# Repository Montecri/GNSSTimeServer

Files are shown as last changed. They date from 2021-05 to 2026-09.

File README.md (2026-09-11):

# <p align="center">Stratum-1 GNSS Time Server Built From Scratch-GNSSTimeServer</p>

<p align="center">
  <!-- Row 1: live repo stats -->
  
  
  
  
  
</p>
<p align="center">
  <!-- Row 2: what the project IS -->
  
  
  
  
  
  
  

<p align="center">
  <a href="https://github.com/Montecri/GNSSTimeServer/releases?q=ntp-rdate-">
    
  </a>
  <a href="https://github.com/Montecri/GNSSTimeServer/releases?q=ptp-master-">
    
  </a>
  <a href="https://github.com/Montecri/GNSSTimeServer/releases?q=ptp-slave-">
    
  </a>
</p>
  
</p>

<p align="center">
  <a href="https://github.com/Montecri/GNSSTimeServer/tree/main/src/PTP/README.md" target="_blank">
    
  </a>
</p>

<p align="center">
  <strong>
    <a href="https://github.com/Montecri/GNSSTimeServer/tree/main/src/PTP/README.md">
      GNSS Time Server: The PTPv2 Edition
    </a>
  </strong>
</p>

<br>

<p align="center"><a href="https://docs.google.com/forms/d/e/1FAIpQLSchZhBenU4u7z4XQDj6ZXXRinHSWwy8loy8uxbl7-j-GinHIg/viewform" target="_blank">
 Answer Survey
 <b>Answer the survey: Crowdfunding for GNSS Time Server</b>
 </a></p>

<br>





## 📡 Ethernet/WiFi enabled, GNSS fed, NTP/RDATE/PTP server based on ESP8266/ESP32 and Arduino

<br>

🎖️ Featured by [Hackaday](https://hackaday.com/2021/07/25/portable-gps-time-server-powered-by-the-esp8266/)

🎖️ Selected for and presented at [Maker Faire Rome 2023](https://makerfairerome.eu/en/exhibitors/?edition=2023&exhibit=2320015)

🎖️ Selected for and presented at [Maker Faire Curitiba 2026](https://www.makerfairecuritiba.com.br/)

<br>

## 📸 Maker Faire Rome 2023 Pictures
<br>

|  |  |  |  |
|:-:|:-:|:-:|:-:|
|  |  |  |  |
|  |  |  |  |

<p align="center">

<br>

"Buy Me A Coffee" (https://www.buymeacoffee.com/cristmon)

<br>

</p>

---

## ✨ Functionalities

- **Internal real-time clock (RTC)** with an integrated temperature-compensated crystal oscillator (TCXO), synched from Global Navigation Satellite System (GNSS) satellites constellation (GPS, BeiDou, GLONASS and Galileo; backed by CR2032 battery)
- **Real-time operating system (RTOS) multi-tasking** (when used with ESP32); core tasks (GNSS synching, Clock updating, processing NTP/RFC868 requests) running with a higher priority than common tasks (display update, PPS led blinking, web page serving)
- **Rich dashboard** with information about MCU, RTC, GNSS, WiFi (uptime, free heap, minimum heap, temperature, version, IP, mac address, network name, network type, signal strength, timestamp, lat, long, lock status, sats, precision, etc)
- **Highly optimized web page** (minimalist single HTML with no external dependency, embedded graphics (as base64 encoded strings, including favicon), embedded script and layout, gzip-compressed - Python conversion/compression script supplied), requiring a password for critical functions. Only 32 Kb in size total, further reduced to ~20Kb through GZip compression. All modern browsers support gzipped pages, the compression takes place before firmware compiling, so no computing cycle is wasted by the device
  - Data separated from layout, once the page is loaded, data will be updated every 5 seconds from a lightweight JSON string, no full page reloads are needed
- **Over-The-Air (OTA)** Web Based firmware upgrade
- **Dual voltage powered**
- **Backup battery** for the whole unit (18650)
- **NTP and RDATE (RFC868)** protocols supported
- **WiFi functionality** as a client or access point
- **10/100 Mbps Ethernet support** (W5500 hardwired TCP/IP embedded Ethernet controller)
- **Syslog logging**
- **Configuration webpage** for WiFi and Syslog, saving to persistent storage (LittleFS)
- **Informative display** with a timestamp, satellites in view, accuracy, WiFi server, IP address
- **Dual function button**, short press switch information on display, long press toggles WiFi
- **Status at a glance**, with dedicated 5mm LEDs for GPS lock, PPS signal, and WiFi status, as well as visible internal leds for charging and GPS module statuses
  - Yellow LED will be on or off to indicate respective WiFi status
  - Green LED will blink/pulsate at different rates to indicate a lock is being acquired and stay steady green when locked
  - Red LED will blink once a second once the lock is acquired, in sync with the PPS signal
- **Diagnostics messages on boot**
  - When turned on, the OLED will first display the reason for the last shutdown (if it was rebooted by the MCU itself due to a power oscillation or other reason or if it was a user-triggered shutdown) and proceed displaying the startup status of each module, so if it gets stuck on boot you can know which module is hanging and troubleshoot faster.

> [!NOTE]
> Please note that some functionalities are available only on ESP32, due to either ESP8266 limitation or the functionality not being backported yet.

---

## 🧰 Parts list

- Amica NodeMCU (ESP8266 / ESP-12) **or** ESP32Duino (ESP32-WROOM-32)
- DS3231 RTC
- **GNSS module. Tested with:** Neo-6m V2 · ATGM336H · ZKMICRO AT6558D · TOPGNSS Allystar TAU1201
- 1.3" SH1106 OLED Display
- **For mains powered:** Hi-Link 5V/3W · Mini-360 DC-DC Buck converter · TP4056 Module · 18650 battery holder · 0.5A/230v fuse · 10D561K varistor
- **For power adapter powered:** 18650 battery shield · 5.5mm x 2.1 mm or any other suitable socket
- **For the ethernet-enabled version:** WIZNet W5500 module
- Resistors (150, 100, and 150 Ohms respectively for above LEDs)
- Switch key and momentary push button

<p align="center"><b>New dashboard screenshot:</b></p>


<p align="center"><b>And the new 3D printable case:</b></p>


<br>

> [!TIP]
> **Check also the Dual Display PIR Enabled branch option:**
> https://github.com/Montecri/GPSTimeServer/tree/Dual-Display

---

## ⚠️ Before you build — read these

<p align="center"><b>   ATTENTION   </b></p>

> [!CAUTION]
> Several DS3231 modules being sold today contain a hazardous design flaw in which it supplies a voltage to the battery cradle regardless if it came with a rechargeable battery or not. If it came with a CR2032 battery (non-rechargeable) the consequence is that it will swell, explode, or worse. If it comes with a LIR2032 battery (rechargeable), the module is fed with 5v will generate an unsafe charging voltage for that battery.
>
> There are workarounds for that so you don't need to toss your module away, the most popular being removing a diode and/or resistor.
>
> There's a long discussion on the thread below about the root cause and possible fixes:
>
> https://forum.arduino.cc/t/zs-042-ds3231-rtc-module/268862/33

<p align="center">
  <b>   GNSS BPS NOTICE   </b>
</p>

> [!IMPORTANT]
> Please note that the vast majority of GNSS modules come pre-configured for 9600 bps serial communication. While this supposedly is a fit for the GPS communication, it may not be enough for other GNSS networks, which work or may work with faster speeds.
>
> So, you will find in the code that I favor 115200 for GNSS module bps speed, which is the practical limit and works great if you set your GNSS module to 10Hz as opposed to the default 1Hz updates, for the modules I tested.
>
> There's a number of applications capable of changing a GNSS module frequency and bps; one I know that works for several module brands is called GnssToolKit3.

---

## 📚 Libraries

```
Libraries:
  paulstoffregen/Time   @ ^1.6
  makuna/RTC            @ ^2.3.5
  mikalhart/TinyGPSPlus @ ^1.0.3
  olikraus/U8g2         @ ^2.28.8
  arcao/Syslog          @ ^2.0.0
```

**Source code based on:**

- http://w8bh.net/avr/clock2.pdf
- https://forum.arduino.cc/t/ntp-time-server/192816

**Contributions from:**

- @mmarkin
- @sjthespian

---

## 🔌 Wiring & power diagrams

<b>ESP8266 Wiring Diagram:</b>

sketch_bb-menor

<br/><br/>

<b>ESP32 Wiring Diagram:</b>

sketch-ESP32-20250308_bb

<br/><br/>

<b>ESP32 With Ethernet Wiring Diagram:</b>

sketch-ESP32_With_ETH-20250308_bb

<br/><br/>

<b>Power Supply Diagram:</b>

power supply - UPDATED_bb-menor

---

📰 https://www.linkedin.com/pulse/iot-maker-tale-stratum-1-time-server-built-from-scratch-monteiro/

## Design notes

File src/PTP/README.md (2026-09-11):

# <p align="center">GNSS Time Servers Built From Scratch - The PTPv2 Edition</p>

<p align="center">
  <!-- Row 1: live repo stats (repo-wide, shields.io can't scope these to a subdirectory) -->
  
  
  
  
  
</p>
<p align="center">
  <!-- Row 2: what THIS subtree IS (PTP Grandmaster + Slave) -->
  
  
  
  
  
  
  
  
  
</p>



<br>

🎖️ Featured by [Hackaday](https://hackaday.com/2026/07/08/this-diy-time-server-is-more-accurate-than-you-need/)

🎖️ Selected for and presented at [Maker Faire Curitiba 2026](https://www.makerfairecuritiba.com.br/)
<br><br>

Two homemade time servers, one obsession: turning a noisy one-pulse-per-second tick from the GPS satellites overhead into a clock the rest of your network can trust. They come from the same workbench and the same stubborn insistence on building from scratch, they differ only in **how precise you need to be**.

- 🛰️ The **GNSS Time Server** speaks **NTP and RDATE** and keeps a whole network honest to the **millisecond**. Portable, battery-backed, WiFi-enabled, happy in a HAM shack, a home lab, or a field bag.
- 📡 The **PTP Grandmaster** speaks **PTPv2 (IEEE 1588-2008)** and disciplines a wired Ethernet segment to the **sub-microsecond**, for industrial automation, telecom, broadcast, finance, and instrumentation, where "close enough" stopped being close enough.

Same maker, same itch, three orders of magnitude apart.

<br>

📰 The story behind both builds, in two parts:
*[An IoT Maker Tale: Stratum-1 Time Server Built From Scratch](https://www.linkedin.com/pulse/iot-maker-tale-stratum-1-time-server-built-from-scratch-monteiro/)*, and its sequel, *[An IoT Maker Tale, Part II: From Stratum-1 NTP to a Sub-Microsecond PTP Grandmaster](https://www.linkedin.com/pulse/iot-maker-tale-part-ii-from-stratum-1-ntprdate-ptpv2-monteiro-ja6ef)*.

<br>

"Buy Me A Coffee" (https://www.buymeacoffee.com/cristmon)

---

## 🧭 Which one is for you?

Both are GNSS-disciplined, self-contained, dissectable-from-the-inside time sources built on inexpensive microcontrollers, with the same maker-friendly DNA an informative OLED, a push button to cycle screens, status LEDs, and a web dashboard. The table is the fastest way to choose; the rest of this README walks through *why* each row is what it is.

| | 🛰️ **GNSS Time Server** | 📡 **PTP Grandmaster** |
| --- | --- | --- |
| **Protocols** | NTP + RDATE (RFC 868) | PTPv2 (IEEE 1588-2008), Layer-2 Ethernet |
| **Typical accuracy** | Milliseconds across the network | **Sub-microsecond** (mean error −74 ns) |
| **Brain** | ESP8266 / ESP32 + Arduino | ESP32-P4 + ESP-IDF |
| **Timestamping** | Software | **Hardware** (ESP32-P4 on-chip PTP-capable EMAC) |
| **Connectivity** | WiFi + 10/100 Ethernet (W5500) | Wired Gigabit Ethernet (IP101 PHY) |
| **Holdover clock** | DS3231 TCXO, battery-backed | On-chip PHC + software servo |
| **Power** | Dual (mains + 18650), portable | USB-C |
| **Field-ready** | Yes, runs on battery, WiFi out of the box | Bench / rack, wired Ethernet by nature |
| **Best for** | Home labs, HAM shacks, general sync, field use | Industrial, telecom, broadcast, finance, instrumentation |

The short version: reach for the **GNSS Time Server** when you want a portable box that keeps any network's clocks accurate and runs anywhere. Reach for the **PTP Grandmaster** when milliseconds aren't enough and you need wired sub-microsecond precision.



<br>

---

## 🛰️ Where time comes from

Both devices start at the same place: the constellation of GPS / GNSS satellites overhead, each carrying atomic clocks accurate to about a second every few hundred million years, a free Stratum-0 reference floating over our heads. A GNSS module locks onto them and emits two things that matter: the current time, and a **Pulse Per Second (PPS)**, a clean (almost) 1 Hz electrical edge marking the top of each second.

That PPS edge is the heartbeat. Everything downstream is a question of how faithfully you can capture it and how cleanly you can pass it on.

- The **GNSS Time Server** disciplines a battery-backed **DS3231 TCXO** real-time clock from the satellites and answers NTP/RDATE requests. The temperature-compensated crystal holds time gracefully during satellite outages.
- The **PTP Grandmaster** goes further: it captures the PPS edge *inside the GPIO interrupt* and uses it to discipline the ESP32-P4's on-chip **PTP Hardware Clock (PHC)** through a software servo, then hardware-timestamps PTP frames as they leave the wire. No external RTC, the servo itself "remembers" the crystal's drift and coasts through brief outages.

The single biggest lever on precision is the GNSS module. A navigation-grade receiver (NEO-6m, ATGM336H) assumes it's moving and constantly re-estimates its position, and that noise rides straight onto the PPS edge. A **timing-mode** receiver like the **AllyStar TAU1201** knows it's stationary and spends its math on the time solution instead, dropping PPS jitter from hundreds of nanoseconds to roughly **10 ns**. The GNSS Time Server works beautifully with either; the PTP Grandmaster's sub-microsecond numbers depend on it.

<p align="center"><a href="http://www.youtube.com/watch?feature=player_embedded&v=QWhQtFGGHVM" target="_blank">
 Watch the video
</a>

---

## ⭐ What both share and where they part ways

Everything below is organized by capability, comparing the two builds side by side. Where a feature belongs to only one device, it's marked 🛰️ (NTP/RDATE) or 📡 (PTP); shared traits are marked 🤝.

### 🔌 Connectivity & protocols

- 🛰️ **NTP and RDATE (RFC 868)** served over WiFi (client *or* access point) and 10/100 Mbps Ethernet via a hardwired **W5500** controller.
- 📡 **PTPv2 over Layer-2 Ethernet** (Annex F) raw frames, no IP/UDP overhead, with two-step **Sync + Follow_Up**, **Announce**, and **Delay_Req / Delay_Resp** exchanges, on wired Gigabit through an **IP101** PHY.
- 📡 **Plug-and-play addressing** DHCP first, automatic static-IP fallback after 15 s if no server replies. (The NTP build offers WiFi configuration via its web page instead.)
- 🤝 Both come up on the network with no hand-holding and announce themselves clearly once linked.

> [!IMPORTANT]
> **PTP belongs on wired Ethernet, never WiFi.** The protocol's sub-microsecond accuracy assumes a deterministic, hardware-timestamped physical layer; WiFi's association, retry, and queueing jitter would swamp it entirely. The NTP/RDATE server, by contrast, is perfectly at home on WiFi, millisecond-class accuracy tolerates it comfortably.

### ⏱️ The clock and its discipline

- 🛰️ **DS3231 TCXO RTC**, satellite-synched and CR2032-backed, with PPS aligning the top-of-second.
- 📡 **On-chip PHC** steered by a three-state software servo (`UNLOCKED → ACQUIRING → LOCKED`): a coarse step on acquisition, a fine residual correction, then a slow **PID loop** whose derivative term tracks the thermal transients of a crystal warming up, hundreds of ppb/sec of drift that an integrator alone is too slow to catch.
- 📡 A **32-sample running-mean averager** (≈5.7× noise reduction) is the servo's working signal, and frequency corrections are **slew-rate-limited** so the servo physically cannot chase a transient faster than the averager smooths it.
- 📡 **TAI ↔ UTC** handling (37 s offset, configurable for future leap seconds).

### 🛰️ GNSS interface & signal diagnostics

- 🤝 **Multi-constellation NMEA** GPS, GLONASS, Galileo, BeiDou (plus QZSS / multi-GNSS GN talker on the PTP build).
- 📡 **PPS captured inside the ISR**, eliminating 10–50 µs of FreeRTOS scheduling jitter that would otherwise be injected straight into the offset measurement.
- 📡 Live **signal-quality telemetry**: per-constellation SNR (avg/min/max), satellites in view vs. used, satellite churn (PRN entries/exits per window), and PPS edge-to-edge jitter (min/max/mean-abs/outliers).
- 📡 **Fix-validity gating** time is only trusted when RMC confirms a valid fix, so a coasting receiver can't feed stale time into the servo.

### 🧭 Grandmaster behaviour (📡 PTP only)

- **Best Master Clock Algorithm (BMCA)** with full priority1 / clockClass / accuracy / variance / priority2 / clockIdentity ordering, so multiple grandmasters can coexist and fail over gracefully.
- A **stability filter** that requires 3 consecutive Announces from the same candidate before changing roles, and a **6-second announce timeout** before reclaiming the master role, together giving the master role a clean hysteresis that shields downstream slaves from needless flapping.
- **Dynamic clock quality** advertising: clockClass 6 / accuracy 0x21 when locked, 7 / 0x23 in holdover, with a 30-second post-holdover settling window so recovering slaves don't rail their servos against a still-settling master.
- **Slave tracking**, up to 8 simultaneous slave clock IDs with a 30-second activity timeout.

### 🛡️ Holdover & resilience

- 🛰️ The **DS3231 TCXO** keeps time through satellite outages; the unit is **dual-powered** (mains + 18650) so it rides out power blips too.
- 📡 **Smart holdover** distinguishes a *sentence-only* outage (NMEA stopped but PPS still alive, preserve all learned servo state) from a *true* PPS loss (re-acquire from scratch).
- 📡 A **self-healing watchdog** can restart the EMAC while preserving PHC continuity across the ~120 ms dead window, slaves see one missed Sync, not a full re-acquire, backed by PHC-freeze and heap-pressure detection, torn-read protection on the PHC second-boundary, and a leak-free pure-arithmetic `timegm`.

### 🖥️ Status at a glance: display, button, LEDs, dashboard

This is the maker-friendly heart both devices share: you can read their health across the room, drill in with one button, or pull up a full dashboard from a browser.

- 🤝 An **OLED display** with a **push button** to cycle informative screens, plus **status LEDs** and a **web dashboard**. No laptop required to know what's going on.
- 🛰️ **Boot diagnostics** report the reason for the last shutdown and the start-up status of each module, so if it ever hangs on boot, you know exactly which module to blame. A **dual-function button** short-presses to switch the display and long-presses to toggle WiFi. Dedicated 5 mm LEDs cover GPS lock, PPS, and WiFi; a rich web dashboard reports MCU / RTC / GNSS / WiFi telemetry (uptime, heap, temperature, IP, MAC, satellites, precision, lat/long, and more), updated every 5 seconds from a lightweight JSON string with no full-page reloads. The page is a single gzip-compressed HTML under ~20 KB with no external dependencies, password-protected for critical functions, and supports **OTA firmware upgrades**.
- 📡 **Five navigable screens** 📊 Main (lock state, UTC, offset, GNSS status, active slaves), ⚙️ Servo (lock duration, quality %, peak spread, frequency adjustment, integrator, PPS count), 📡 GNSS Signal (verdict, SNR range, SVs in view vs. used, fix quality), 🌐 Network (link, IP, uptime, heap), and 🔧 Timing Config (TAU1201 configurator status, which **auto-jumps into view on failure**). The lock LED has five distinct patterns, off (no link), slow blink (acquiring), solid (locked), heartbeat (holdover), fast blink (fault), and a second LED pulses on **every PPS edge**.

---

## 🧰 Parts

### 🛰️ GNSS Time Server

- Amica NodeMCU (ESP8266 / ESP-12) **or** ESP32Duino (ESP32-WROOM-32)
- DS3231 RTC
- GNSS module, tested with Neo-6m V2, ATGM336H, ZKMICRO AT6558D, TOPGNSS AllyStar TAU1201
- 1.3" SH1106 OLED display
- **Mains-powered:** Hi-Link 5V/3W · Mini-360 DC-DC buck · TP4056 module · 18650 holder · 0.5 A/230 V fuse · 10D561K varistor
- **Adapter-powered:** 18650 battery shield · 5.5 × 2.1 mm (or suitable) socket
- **Ethernet version:** WIZnet W5500 module
- Resistors (150, 100, 150 Ω for the LEDs) · and a momentary push button

### 📡 PTP Grandmaster

- **JC-ESP32P4-M3-DEV (Guition board)** (Espressif), hardware PTP-capable EMAC
- **AllyStar TAU1201** GNSS module, configured in timing mode
- **IP101** Ethernet PHY (on-board on the EV-Board variant used here)
- 1.3″ SH1106 OLED (128×64, I²C, address `0x78`)
- Momentary push button · 5 mm LEDs (lock + PPS) with current-limiting resistors
- Active GPS antenna with clear sky view
- RJ45 cable (Cat 5e+, for back-to-back testing - No crossover needed for connecting two JC-ESP32P4-M3-DEV since they are MDI/MDIX)
- 5 V supply (USB-C)

> [!TIP]
> The **TAU1201 is the single highest-impact part choice** in either build, and the make-or-break one for the PTP grandmaster. A navigation-grade receiver works, the firmware accepts NMEA from any of them, but PPS jitter will be hundreds of nanoseconds rather than ~10 ns, and the achievable accuracy scales with it. If the budget allows, fit the TAU1201.

> [!NOTE]
> On the NTP/RDATE build, some functionalities are ESP32-only, due either to ESP8266 limitations or features not yet backported.

---

## 🛠️ Building each one

The two devices use **different toolchains** this is the clearest practical fork between them.

**🛰️ GNSS Time Server: Arduino / PlatformIO**

```
Libraries:
  paulstoffregen/Time @ ^1.6
  makuna/RTC          @ ^2.3.5
  mikalhart/TinyGPSPlus @ ^1.0.3
  olikraus/U8g2       @ ^2.28.8
  arcao/Syslog        @ ^2.0.0
```

**📡 PTP Grandmaster: ESP-IDF 5.5.4**

```
Libraries:
  olikraus/U8g2           @ ^2.36.19
  mkfrey/u8g2-hal-esp-idf @ ^v3-compat
```

> [!IMPORTANT]
> On its first boot in a new location, the PTP grandmaster spends a few minutes on a **TAU1201 position survey** before timing-mode engages, screen 5 shows progress. This is part of the timing mode process activation, it will compute it's current location during this window and then revert to timing only calculation.

---

## 🧪 Measuring sub-microsecond honestly (📡 PTP)

A grandmaster's accuracy claim is only as good as the instrument measuring it. A software-timestamping slave on a generic PC would drown sub-microsecond behaviour in its own kernel jitter, so the measurement instrument has to be at least as good as the device under test. The project, therefore, includes a **companion slave unit on identical ESP32-P4 hardware**, with its own hardware-timestamped state machine, servo, OLED, button, LEDs, and web dashboard reporting offset, path delay, and lock quality.

```
   ┌──────────────────┐                    ┌──────────────────┐
   │  GPS antenna     │                    │                  │
   │       │          │                    │                  │
   │       ▼          │   Ethernet cable   │                  │
   │  ESP32-P4 GM     │◄──────────────────►│  ESP32-P4 Slave  │
   │  (this repo)     │       100 Mbps     │  (sibling repo)  │
   │                  │                    │                  │
   │  OLED + LEDs     │                    │  OLED + LEDs     │
   └──────────────────┘                    └──────────────────┘
```

Captured by that slave, on a typical evening with the antenna on the balcony:

| Metric | Value |
| --- | --- |
| 🎯 Within ±300 ns of true GPS time | ~30% |
| 🎯 Within ±1 µs | ~74% |
| 🎯 Within ±2 µs | ~89% |
| 📏 Mean error | −74 ns |
| ⏱️ Cold-boot lock time | ~30 s |
| 🛰️ Raw PPS jitter (TAU1201, timing mode) | ~10 ns |
| 🔄 EMAC-restart PHC continuity | < 1 µs residual |

For context, commercial PTP grandmasters delivering similar numbers typically start north of **US$2,000**. The bill of materials here, for *both* master and slave, is closer to a nice dinner.

> [!NOTE]
> **What's next:** a **PTP-capable switch** (transparent- or boundary-clock function preferred) to run multiple slaves against the master at once, and a third unit configured as a boundary clock. Switched-network testing is where the interesting questions surface, master load scaling, BMCA failover under real witnesses, switch-induced residence delay. Yes, I understand commercial units come with high-quality OCXO parts, rubidium oscillators, certifications, etc, but still...

---

## ⚠️ Before you build, read these

<p align="center"><b>   ATTENTION   </b></p>

🚨 **GNSS serial speed (both builds).** Most GNSS modules ship at 9600 bps. That's fine for GPS alone, but can be too slow for multi-constellation work. The code favors **115200 bps**, which is the practical limit and pairs well with raising the module from 1 Hz to 10 Hz updates. Tools like *GnssToolKit3* can change a module's rate and baud across several brands.

🚨 **PTP needs wired Ethernet (📡 PTP).** Never attempt PTP over WiFi, association/retry/queueing jitter dwarfs the protocol's accuracy budget and no servo tuning can recover it.

🚨 **TAU1201 timing mode after a survey (📡 PTP).** First boot in a new location takes several minutes to reach `READY` while the module surveys its position. Survey window is configurable in `allystar_timing.h`.

🚨 **Domain 0 by default (📡 PTP).** The grandmaster announces on PTP domain 0 and will join the BMCA election on any network already running PTP there. Set a different domain in `main.c` (`#define PTP_DOMAIN`) before deploying alongside existing infrastructure.

🚨 **GNSS time is TAI, not UTC (📡 PTP).** The firmware advertises `currentUtcOffset = 37` and sets `PTP_TIMESCALE` on the wire. Slave software that treats PTP timestamps as UTC will be off by the TAI−UTC offset. This is correct per IEEE 1588, just worth knowing when integrating with software that's never met a proper grandmaster.

---

## 🤖 A note on AI tooling

The first build, three years ago, was stitched together by hand from two PDFs and an Arduino-forum thread. The second would not have reached this caliber, in the time one person had, without the generation of AI tools available in 2026. Yes, the code is heavily built by AI. Don't like it? Go there and fix!

The PID tuning still had to be measured against reality. The interrupt path still had to be debugged on real hardware. The architectural decisions are still mine to defend. But AI compressed weeks of reading and experimenting into hours and let a single maker take on the scope of *two* firmware codebases, grandmaster and slave, in one project cycle. For anyone hesitating to start something that feels too large: the tools have changed, and the barrier is lower than you think.

---

## 📚 Related & lineage

- 🛰️ [**GNSSTimeServer**](https://github.com/Montecri/GNSSTimeServer): the NTP/RDATE server, featured by Hackaday and exhibited at Maker Faire Rome 2023
- 🔀 [**Dual Display PIR-Enabled branch**](https://github.com/Montecri/GPSTimeServer/tree/Dual-Display): an alternative build of the NTP/RDATE server
- 📡 **PTPGrandmaster**: the sub-microsecond follow-up (this project)
- 📡 **PTPGrandmasterSlave**: the companion slave used to validate the PTP numbers above

---

## 🙏 Acknowledgements

The NTP/RDATE server stands on the shoulders of [w8bh.net](http://w8bh.net/avr/clock2.pdf) and the [Arduino NTP time-server thread](https://forum.arduino.cc/t/ntp-time-server/192816), with contributions from @mmarkin and @sjthespian. The PTP grandmaster stands on the open-source PTP community, Espressif's ESP-IDF PTP examples, and the IEEE 1588 specification itself. And all stand on everyone who sent feedback over the years and asked me to pursue a PTP version of the GNSSTimeServer, that community is the reason there's a Part II.

---

"Buy Me A Coffee" (https://www.buymeacoffee.com/cristmon)

73 📻

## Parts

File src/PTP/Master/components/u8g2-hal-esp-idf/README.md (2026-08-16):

# U8g2 compatibility component for ESP-IDF on ESP32
## Note
This is effectively a fork of the U8G2 code that is part of Neil Kolban's excellent `esp32-snippets` repository. It can be found 
[here](https://github.com/nkolban/esp32-snippets/tree/master/hardware/displays/U8G2).

His repository is no longer maintained and using a single directory as submodule is not possible. So I copied the relevant
files and made them a functional component for ESP-IDF by creating the required build system files.

This component should compile on ESP-IDF versions 5.x upward. Older versions are not supported.

## Description
There is an excellent open source library called `u8g2` that can be found on Github here:

[https://github.com/olikraus/u8g2](https://github.com/olikraus/u8g2)

The purpose of the library is to provide a display independent driver layer for monochrome displays including LCD and OLED.
The library "knows" how to driver the underlying displays as well as providing drawing primitives including text, fonts, lines and
other geometrical shapes.

A version of the library is available in cleanly compiling C and compiles without incident on the ESP32-IDF framework.

However, since the library is agnostic of MCU environments and will work on a variety of boards, there has to be a mapping from
the functions expected by the library to the underlying MCU board hardware. This includes driving GPIOs, I2C, SPI and more.

The code in this folder provides a mapping from U8g2 to the ESP32 ESP-IDF. This should be included in your build of U8g2 applications.

To use with the ESP32, we must invoke the `u8g2_esp32_hal_init()` function before invoking any of the normal U8g2 functons.  What
this call does is tell the ESP32 what pins we wish to map.  Here is an example of SPI use:

```
u8g2_esp32_hal_t u8g2_esp32_hal = U8G2_ESP32_HAL_DEFAULT;
u8g2_esp32_hal.bus.spi.clk   = PIN_CLK;
u8g2_esp32_hal.bus.spi.mosi  = PIN_MOSI;
u8g2_esp32_hal.bus.spi.cs    = PIN_CS;
u8g2_esp32_hal.dc    = PIN_DC;
u8g2_esp32_hal.reset = PIN_RESET;
u8g2_esp32_hal_init(u8g2_esp32_hal);
```

and here is an example of I2C use:

```
u8g2_esp32_hal_t u8g2_esp32_hal = U8G2_ESP32_HAL_DEFAULT;
u8g2_esp32_hal.bus.i2c.sda = PIN_SDA;
u8g2_esp32_hal.bus.i2c.scl = PIN_SCL;
u8g2_esp32_hal_init(u8g2_esp32_hal);
```

Note: For I2C, after calling the display specific setup, invoke:

```
u8x8_SetI2CAddress(&u8g2.u8x8,<address>);
``` 

Note that `<address>` is the I2C address already shifted left to include the read/write flag.  For example, if you are using an SSD1305, instead of supplying the address `0x3C` which would be `0011 1100` supply `0x78` which would be `0111 1000`.

The function takes as input a `u8g2_esp32_hal` structure instance which has the logical pins that U8g2 needs mapped to the
physical pins on the ESP32 that we wish to use.  If we don't use a specific pin for our specific display, set the value to
be `U8G2_ESP32_HAL_UNDEFINED` which is the default initialization value.

Remember, ESP32 pins are not hard-coded to functions and as such, all the GPIO pins on the ESP32 are open for use.  Following
this initialization, we can use U8g2 as normal and described in the U8g2 documentation.

## Installation
To use the actual U8g2 library in your ESP32 project, perform the following steps:

1. Create a directory called `components` in your main project directory.
2. Change into the `components` directory.
3. Run `git clone https://github.com/mkfrey/u8g2-hal-esp-idf.git` to bring in the latest copy of this library.
4. Run `git clone https://github.com/olikraus/u8g2.git` to bring in a the latest copy of u8g2 library.

If your project itself is a git repository, you should consider using `git submodule add` instead of cloning.

## Development
While in principal, there should be nothing specific needed beyond this addition to make U8g2 work on the ESP32, only a small
number of boards have been tested.

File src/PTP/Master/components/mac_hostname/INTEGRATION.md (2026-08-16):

# mac_hostname — deterministic, fully reversible MAC → hostname

Turns the device's Ethernet MAC into a stable, human-friendly hostname
(`prefix-title-first-last`, e.g. `fabled-roper-susanda-perrhale`) and
back. The mapping is **bijective over the entire 2^48 MAC space**:
every MAC yields a distinct hostname, and any generated hostname
decodes to exactly its MAC — no collisions, no lookup registry.

## Layout in the project

```
your-project/
├── main/
│   └── main.c                     <- one buffer-size edit, see below
└── components/
    └── mac_hostname/
        ├── CMakeLists.txt
        ├── include/
        │   └── mac_hostname.h     <- public API
        ├── mac_hostname.c         <- codec (Feistel + encode + decode)
        ├── mac_hostname_esp.c     <- mac_hostname_get / mac_hostname_apply
        ├── name_data.c            <- AUTOGENERATED tables (~10 KB flash)
        ├── name_data.h            <- AUTOGENERATED struct + externs
        ├── INTEGRATION.md         <- this file
        └── tools/                 <- not compiled into the firmware
            ├── name_components.py <- curated word/stem/ending lists
            ├── emit_c_data.py     <- regenerates name_data.c/h
            ├── sample_names.py    <- PC codec + full self-test
            ├── emit_c_data.json   <- table dump used by sample_names.py
            └── host_selftest.c    <- PC test of the real C sources
```

No top-level CMakeLists.txt change is needed: ESP-IDF auto-discovers
`components/`, and the `main` component automatically depends on every
discovered component. (If your `main/CMakeLists.txt` lists explicit
`PRIV_REQUIRES`, add `mac_hostname` there.)

## Required edit in main.c

The v3 scheme's worst-case "first-last" OLED line is 17 chars + NUL:

```c
static char g_host_line2[16];   /* before */
static char g_host_line2[24];   /* after  */
```

`g_host_line1[24]` and `g_hostname[MAC_HOSTNAME_BUF_LEN]` are already
correctly sized. Nothing else in main.c changes —
`mac_hostname_get()`, `mac_hostname_apply()` and
`mac_hostname_display_lines()` keep their signatures.

Kconfig: `CONFIG_LWIP_MAX_HOSTNAME_LEN` must be >= 32 (hostnames are
15..31 chars).

## How it works

`MAC --feistel_forward--> 48-bit index --split--> 8|7|17|16 bits`

| bits | token  | construction |
|---|---|---|
| 8 | prefix | 256 real adjectives (≤ 6 ch) |
| 7 | title  | 128 real English roles/ranks (≤ 6 ch) |
| 17 | first  | 256 stems × 512 endings (3–8 ch) |
| 16 | last | 256 roots × 256 suffixes (3–8 ch) |

First/last names are composed, not stored: the stem tables are
**prefix-free** (no stem is a prefix of another), which makes
`stem+ending` concatenation provably injective and lets the decoder
recover the split with a deterministic prefix scan. Decoding is
case-insensitive. Worst-case dashed length is 31 (+ NUL = 32).

## Regenerating or tuning the tables

The component lists in `tools/name_components.py` are plain curated
lists — edit to taste, then:

```
cd components/mac_hostname/tools
python3 emit_c_data.py          # re-proves all invariants, writes
cp name_data.c name_data.h ..   # tables next to the sources
python3 sample_names.py test    # full self-test (bijectivity, 100k)
```

`emit_c_data.py` machine-checks every invariant before writing
anything: exact table sizes, prefix-freeness, exhaustive uniqueness of
all 2^17 + 2^16 concatenations, the 31-char worst case and the 3-char
minimum. If an edit breaks a proof, it refuses to emit.

Note: editing the tables (or the Feistel keys in `emit_c_data.py`)
changes every device's hostname on the next flash.

## PC-side verification

```
cd components/mac_hostname
gcc -Wall -Wextra -O2 -Iinclude -I. -o /tmp/mh_test \
    mac_hostname.c name_data.c tools/host_selftest.c && /tmp/mh_test
```

Runs the real firmware sources on the host: sample MACs, round-trips,
case-insensitive decode, display-line buffer checks, and 100 000
random MACs verified unique and reversible. `sample_names.py` is the
independent Python implementation; both produce identical output
(e.g. `dc:1e:d5:f8:b2:d8 → dulcet-keeper-vicant-pecklund`), so you can
decode a hostname seen in DHCP/mDNS back to its MAC on a PC with
`sample_names.py`, or on-device with `mac_hostname_to_mac()`.

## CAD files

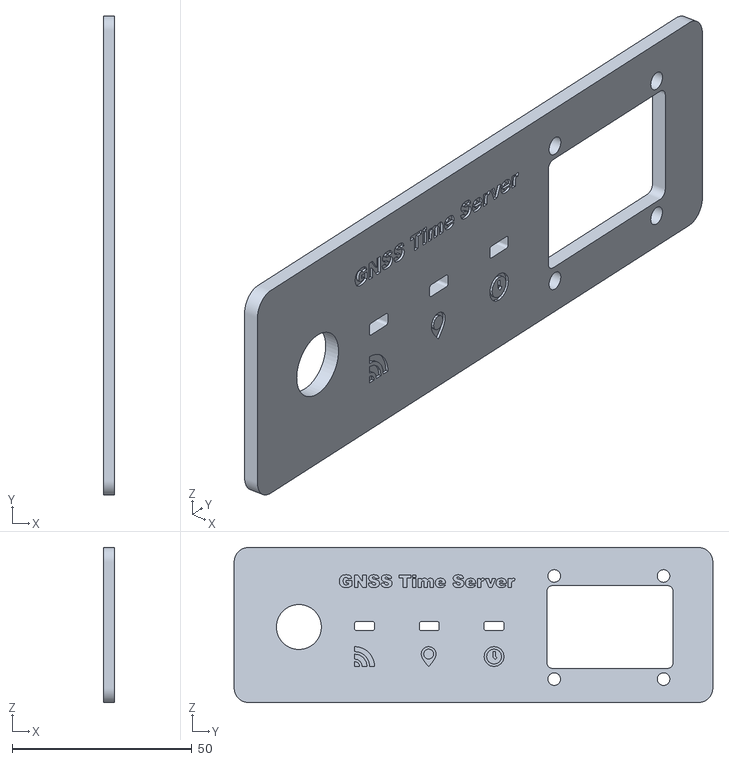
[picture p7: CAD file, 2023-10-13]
resources/3DPrintableCase/Case_Ver2-FPanel.stl
3.00 x 133.1 x 43.1

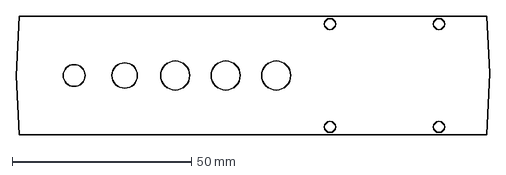
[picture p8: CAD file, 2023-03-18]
resources/painel_frontal-v4.DXF
132.0 x 33.0 mm

src/PTP/Master/components/u8g2/sys/arduino/u8g2_full_buffer/SwitchBox/board.dxf
60
40
52
8
24
80
30
32
25
100
190
4
12
6
14

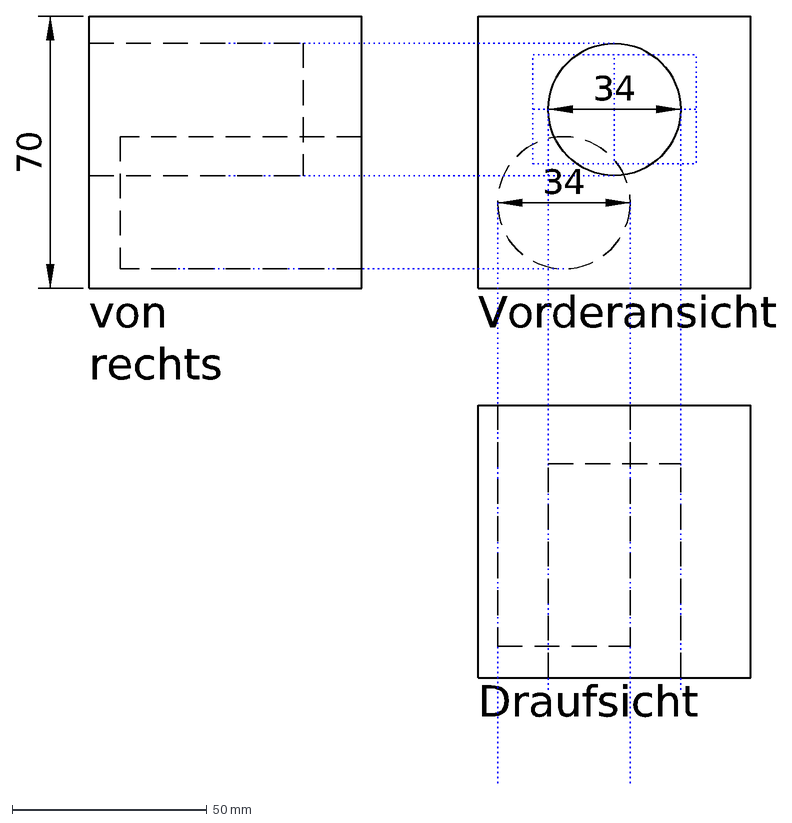
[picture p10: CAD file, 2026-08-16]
src/PTP/Master/components/u8g2/sys/arm/stm32l031x6/clock_cube.dxf
Draufsicht
Vorderansicht
von rechts
70
34

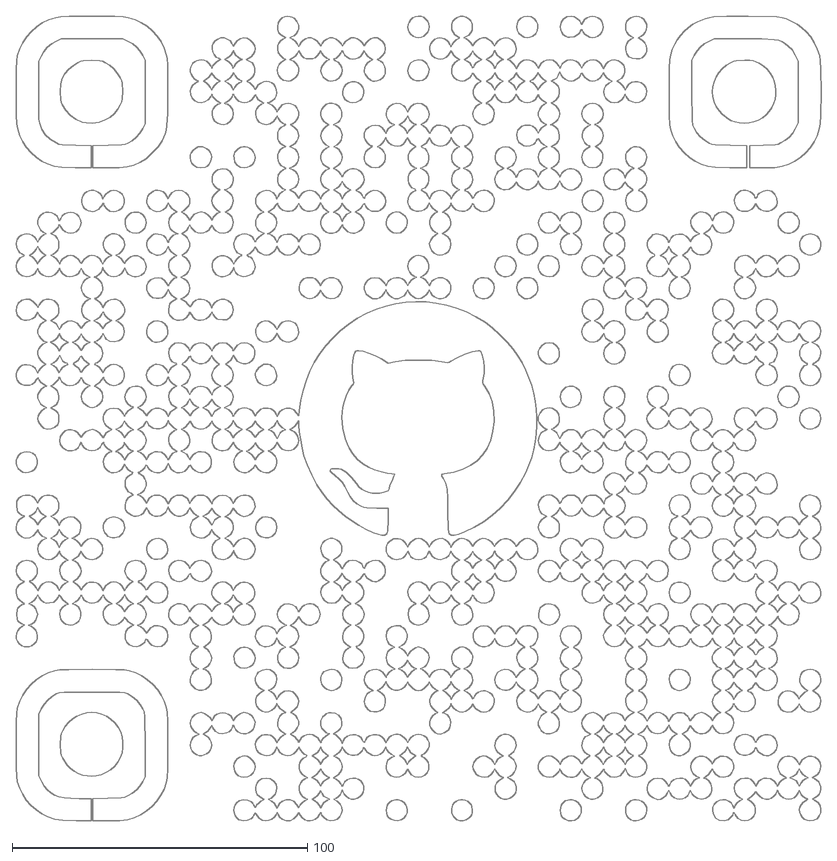
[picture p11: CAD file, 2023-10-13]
src/PTP/resources/qr-code6.dxf
272.8 x 272.8

src/PTP/Slave/components/u8g2/sys/arm/stm32l031x6/clock.dxf
65
32
28
16
Draufsicht
Vorderansicht
von unten
von rechts
von links
14
6
45
60
30
20
8
35
75
55
10
12

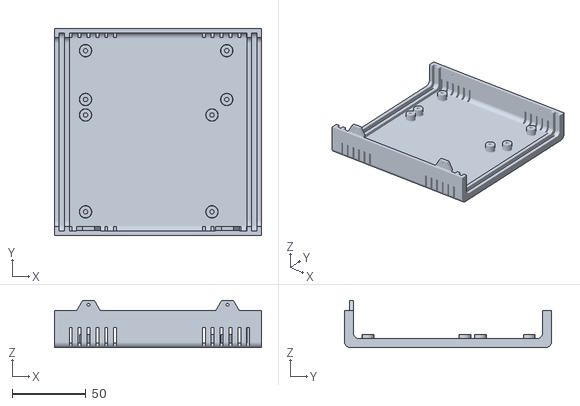
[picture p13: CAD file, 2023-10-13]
resources/3DPrintableCase/Case_Ver2-Bottom.stl
140.0 x 140.0 x 31.9

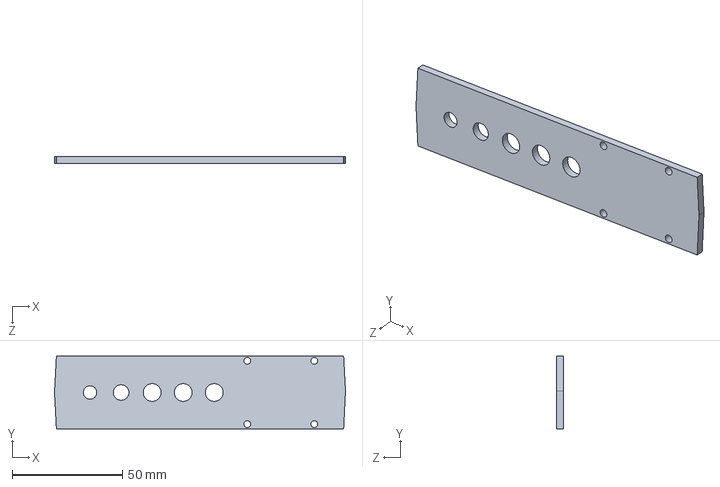
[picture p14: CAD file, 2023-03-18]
resources/painel_frontal-v4-perfurado.SLDPRT
132.0 x 33.0 x 3.00 mm

src/PTP/Master/components/u8g2/sys/arm/stm32l031x6/clock_2.dxf
65
Draufsicht
Vorderansicht
von unten
von rechts
von links
14
30
32
35
75
55
10
12
16
11
22
34
28
29
18
93
19
43
15
68
60
57
150
Holzbohrer: 2.5, 8, 10, 12, 16, 32mm
8
7
6
2.5mm

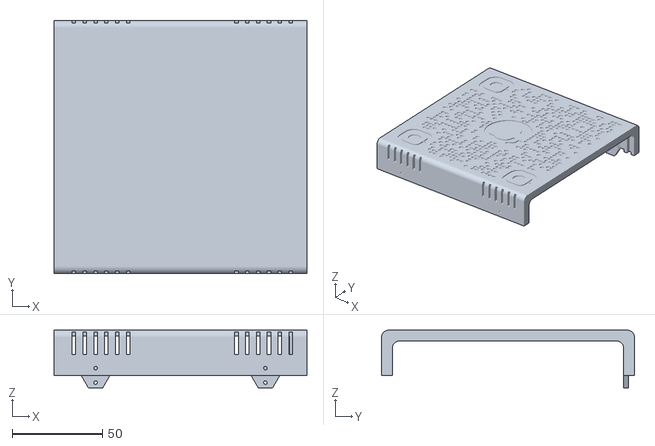
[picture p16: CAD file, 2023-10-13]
resources/3DPrintableCase/Case_Ver2-Top_Github-QR_Code.stl
140.0 x 140.0 x 31.9

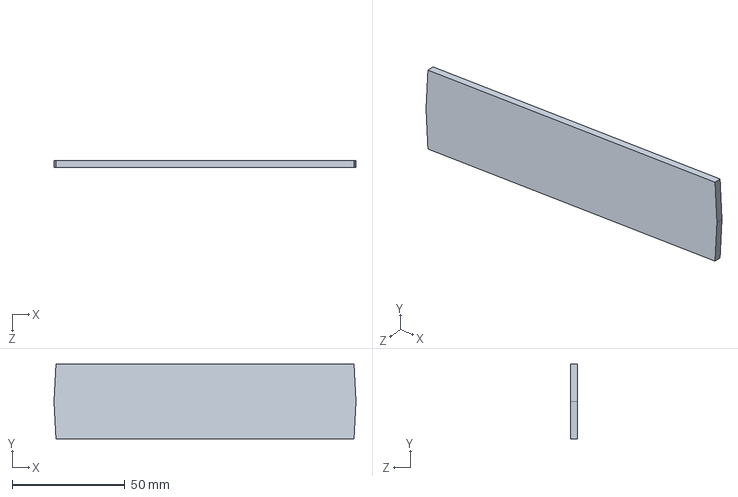
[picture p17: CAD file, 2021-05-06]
resources/painel_frontal_dimensoes.SLDPRT
133.7 x 33.0 x 3.00 mm

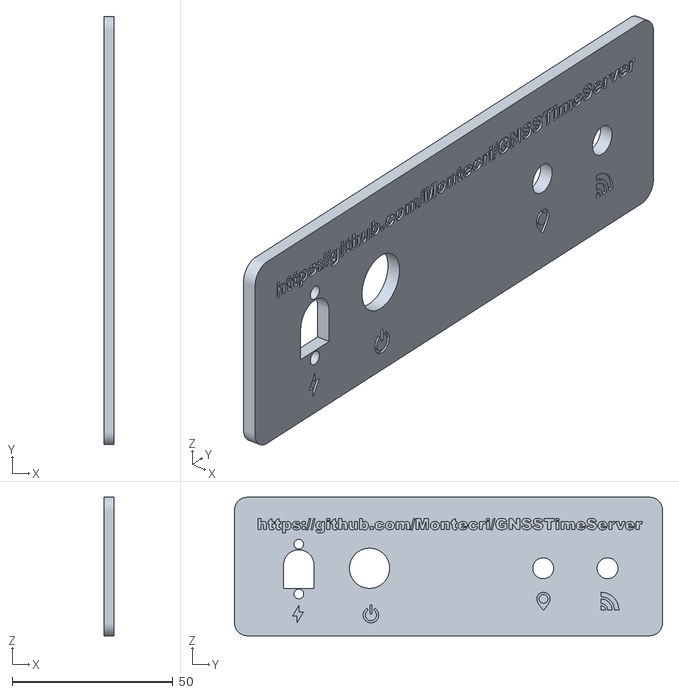
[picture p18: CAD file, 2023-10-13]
resources/3DPrintableCase/Case_Ver2-BPanel.stl
3.00 x 133.1 x 43.1

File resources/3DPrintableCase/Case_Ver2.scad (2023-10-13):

/*//////////////////////////////////////////////////////////////////
              -    FB Aka Heartman/Hearty 2016     -                   
              -   http://heartygfx.blogspot.com    -                  
              -       OpenScad Parametric Box      -                     
              -         CC BY-NC 3.0 License       -                      
////////////////////////////////////////////////////////////////////                                                                                                             
12/02/2016 - Fixed minor bug 
28/02/2016 - Added holes ventilation option                    
09/03/2016 - Added PCB feet support, fixed the shell artefact on export mode. 

*/////////////////////////// - Info - //////////////////////////////

// All coordinates are starting as integrated circuit pins.
// From the top view :

//   CoordD           <---       CoordC
//                                 ^
//                                 ^
//                                 ^
//   CoordA           --->       CoordB


////////////////////////////////////////////////////////////////////


////////// - Paramètres de la boite - Box parameters - /////////////

/* [Box dimensions] */
// - Longueur - Length  
  Length        = 140;       
// - Largeur - Width
  Width         = 140;                     
// - Hauteur - Height  
  Height        = 50;  
// - Epaisseur - Wall thickness  
  Thick         = 3;//[2:5]  
  
/* [Box options] */
// - Diamètre Coin arrondi - Filet diameter  
  Filet         = 4;//[0.1:12] 
// - lissage de l'arrondi - Filet smoothness  
  Resolution    = 50;//[1:100] 
// - Tolérance - Tolerance (Panel/rails gap)
  m             = 0.9;
// Pieds PCB - PCB feet (x4) 
  PCBFeet       = 1;// [0:No, 1:Yes]
  PCBFeet2       = 1;// [0:No, 1:Yes]
// - Decorations to ventilation holes
  Vent          = 1;// [0:No, 1:Yes]
// - Decoration-Holes width (in mm)
  Vent_width    = 2;   


  
/* [PCB_Feet] */
//All dimensions are from the center foot axis

// - Coin bas gauche - Low left corner X position
PCBPosX         = 5;
// - Coin bas gauche - Low left corner Y position
PCBPosY         = 3;
// - Longueur PCB - PCB Length
PCBLength       = 85.5;
// - Largeur PCB - PCB Width
PCBWidth        = 65.5;
// - Heuteur pied - Feet height
FootHeight      = 10;
// - Diamètre pied - Foot diameter
FootDia         = 8;
// - Diamètre trou - Hole diameter
FootHole        = 3;  
  
PCBPosX2         = 5;
// - Coin bas gauche - Low left corner Y position
PCBPosY2         = 79;
// - Longueur PCB - PCB Length
PCBLength2       = 95.5;
// - Largeur PCB - PCB Width
PCBWidth2        = 33;
// - Heuteur pied - Feet height
FootHeight2      = 10;
// - Diamètre pied - Foot diameter
FootDia2         = 8;
// - Diamètre trou - Hole diameter
FootHole2        = 3; 

/* [STL element to export] */
//Coque haut - Top shell
TShell          = 1;// [0:No, 1:Yes]
//Coque bas- Bottom shell
BShell          = 1;// [0:No, 1:Yes]
//Panneau avant - Front panel
FPanL           = 1;// [0:No, 1:Yes]
//Panneau arrière - Back panel  
BPanL           = 1;// [0:No, 1:Yes]


  
/* [Hidden] */
// - Couleur coque - Shell color  
Couleur1        = "Orange";       
// - Couleur panneaux - Panels color    
Couleur2        = "OrangeRed";    
// Thick X 2 - making decorations thicker if it is a vent to make sure they go through shell
Dec_Thick       = Vent ? Thick*2 : Thick; 
// - Depth decoration
Dec_size        = Vent ? Thick*2 : 0.8;





/////////// - Boitier générique bord arrondis - Generic rounded box - //////////

module RoundBox($a=Length, $b=Width, $c=Height){// Cube bords arrondis
                    $fn=Resolution;            
                    translate([0,Filet,Filet]){  
                    minkowski (){                                              
                        cube ([$a-(Length/2),$b-(2*Filet),$c-(2*Filet)], center = false);
                        rotate([0,90,0]){    
                        cylinder(r=Filet,h=Length/2, center = false);
                            } 
                        }
                    }
                }// End of RoundBox Module

      
////////////////////////////////// - Module Coque/Shell - //////////////////////////////////         

module Coque(){//Coque - Shell  
    Thick = Thick*2;  
    difference(){    
        difference(){//sides decoration
            union(){    
                     difference() {//soustraction de la forme centrale - Substraction Fileted box
                      
                        difference(){//soustraction cube median - Median cube slicer
                            union() {//union               
                            difference(){//Coque    
                                RoundBox();
                                translate([Thick/2,Thick/2,Thick/2]){     
                                        RoundBox($a=Length-Thick, $b=Width-Thick, $c=Height-Thick);
                                        }
                                        }//Fin diff Coque                            
                                difference(){//largeur Rails        
                                     translate([Thick+m,Thick/2,Thick/2]){// Rails
                                          RoundBox($a=Length-((2*Thick)+(2*m)), $b=Width-Thick, $c=Height-(Thick*2));
                                                          }//fin Rails
                                     translate([((Thick+m/2)*1.55),Thick/2,Thick/2+0.1]){ // +0.1 added to avoid the artefact
                                          RoundBox($a=Length-((Thick*3)+2*m), $b=Width-Thick, $c=Height-Thick);
                                                    }           
                                                }//Fin largeur Rails
                                    }//Fin union                                   
                               translate([-Thick,-Thick,Height/2]){// Cube à soustraire
                                    cube ([Length+100, Width+100, Height], center=false);
                                            }                                            
                                      }//fin soustraction cube median - End Median cube slicer
                               translate([-Thick/2,Thick,Thick]){// Forme de soustraction centrale 
                                    RoundBox($a=Length+Thick, $b=Width-Thick*2, $c=Height-Thick);       
                                    }                          
                                }                                          


                difference(){// wall fixation box legs
                    union(){
                        translate([3*Thick +5,Thick,Height/2]){
                            rotate([90,0,0]){
                                    $fn=6;
                                    cylinder(d=16,Thick/2);
                                    }   
                            }
                            
                       translate([Length-((3*Thick)+5),Thick,Height/2]){
                            rotate([90,0,0]){
                                    $fn=6;
                                    cylinder(d=16,Thick/2);
                                    }   
                            }

                        }
                            translate([4,Thick+Filet,Height/2-57]){   
                             rotate([45,0,0]){
                                   cube([Length,40,40]);    
                                  }
                           }
                           translate([0,-(Thick*1.46),Height/2]){
                                cube([Length,Thick*2,10]);
                           }
                    } //Fin fixation box legs
            }

        union(){// outbox sides decorations
            
            for(i=[0:Thick:Length/4]){

                // Ventilation holes part code submitted by Ettie - Thanks ;) 
                    translate([10+i,-Dec_Thick+Dec_size,1]){
                    cube([Vent_width,Dec_Thick,Height/4]);
                    }
                    translate([(Length-10) - i,-Dec_Thick+Dec_size,1]){
                    cube([Vent_width,Dec_Thick,Height/4]);
                    }
                    translate([(Length-10) - i,Width-Dec_size,1]){
                    cube([Vent_width,Dec_Thick,Height/4]);
                    }
                    translate([10+i,Width-Dec_size,1]){
                    cube([Vent_width,Dec_Thick,Height/4]);
                    }
  
                
                    }// fin de for
               // }
                }//fin union decoration
            }//fin difference decoration
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

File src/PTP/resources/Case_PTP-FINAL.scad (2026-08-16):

/*//////////////////////////////////////////////////////////////////
              -    FB Aka Heartman/Hearty 2016     -                   
              -   http://heartygfx.blogspot.com    -                  
              -       OpenScad Parametric Box      -                     
              -         CC BY-NC 3.0 License       -                      
////////////////////////////////////////////////////////////////////                                                                                                             
12/02/2016 - Fixed minor bug 
28/02/2016 - Added holes ventilation option                    
09/03/2016 - Added PCB feet support, fixed the shell artefact on export mode. 

09.Jul.2026 - Modified for PTP box by Cristiano Monteiro <cristianomonteiro@gmail.com>

*/////////////////////////// - Info - //////////////////////////////

// All coordinates are starting as integrated circuit pins.
// From the top view :

//   CoordD           <---       CoordC
//                                 ^
//                                 ^
//                                 ^
//   CoordA           --->       CoordB


////////////////////////////////////////////////////////////////////


////////// - Paramètres de la boite - Box parameters - /////////////

/* [Box dimensions] */
// - Longueur - Length  
  Length        = 120;       
// - Largeur - Width
  Width         = 120;                     
// - Hauteur - Height  
  Height        = 50;  
// - Epaisseur - Wall thickness  
  Thick         = 3;//[2:5]  
  
/* [Box options] */
// - Diamètre Coin arrondi - Filet diameter  
  Filet         = 4;//[0.1:12] 
// - lissage de l'arrondi - Filet smoothness  
  Resolution    = 50;//[1:100] 
// - Tolérance - Tolerance (Panel/rails gap)
  m             = 0.9;
// Pieds PCB - PCB feet (x4) 
  PCBFeet       = 0;// [0:No, 1:Yes]
  PCBFeet2       = 0;// [0:No, 1:Yes]
// - Decorations to ventilation holes
  Vent          = 1;// [0:No, 1:Yes]
// - Decoration-Holes width (in mm)
  Vent_width    = 2;   


  
/* [PCB_Feet] */
//All dimensions are from the center foot axis

// - Coin bas gauche - Low left corner X position
PCBPosX         = 1.3;
// - Coin bas gauche - Low left corner Y position
PCBPosY         = 19.4;
// - Longueur PCB - PCB Length
PCBLength       = 92;
// - Largeur PCB - PCB Width
PCBWidth        = 62;
// - Heuteur pied - Feet height
FootHeight      = 10;
// - Diamètre pied - Foot diameter
FootDia         = 8;
// - Diamètre trou - Hole diameter
FootHole        = 2;  

// Feet distance from PCB border
FeetDistBorder = 2.8;
  
PCBPosX2         = 5;
// - Coin bas gauche - Low left corner Y position
PCBPosY2         = 79;
// - Longueur PCB - PCB Length
PCBLength2       = 95.5;
// - Largeur PCB - PCB Width
PCBWidth2        = 33;
// - Heuteur pied - Feet height
FootHeight2      = 10;
// - Diamètre pied - Foot diameter
FootDia2         = 8;
// - Diamètre trou - Hole diameter
FootHole2        = 3; 

/* [STL element to export] */
//Coque haut - Top shell
TShell          = 1;// [0:No, 1:Yes]
//Coque bas- Bottom shell
BShell          = 1;// [0:No, 1:Yes]
//Panneau avant - Front panel
FPanL           = 1;// [0:No, 1:Yes]
//Panneau arrière - Back panel  
BPanL           = 1;// [0:No, 1:Yes]


  
/* [Hidden] */
// - Couleur coque - Shell color  
Couleur1        = "Orange";       
// - Couleur panneaux - Panels color    
Couleur2        = "OrangeRed";    
// Thick X 2 - making decorations thicker if it is a vent to make sure they go through shell
Dec_Thick       = Vent ? Thick*2 : Thick; 
// - Depth decoration
Dec_size        = Vent ? Thick*2 : 0.8;





/////////// - Boitier générique bord arrondis - Generic rounded box - //////////

module RoundBox($a=Length, $b=Width, $c=Height){// Cube bords arrondis
                    $fn=Resolution;            
                    translate([0,Filet,Filet]){  
                    minkowski (){                                              
                        cube ([$a-(Length/2),$b-(2*Filet),$c-(2*Filet)], center = false);
                        rotate([0,90,0]){    
                        cylinder(r=Filet,h=Length/2, center = false);
                            } 
                        }
                    }
                }// End of RoundBox Module

      
////////////////////////////////// - Module Coque/Shell - //////////////////////////////////         

module Coque(){//Coque - Shell  
    Thick = Thick*2;  
    difference(){    
        difference(){//sides decoration
            union(){    
                     difference() {//soustraction de la forme centrale - Substraction Fileted box
                      
                        difference(){//soustraction cube median - Median cube slicer
                            union() {//union               
                            difference(){//Coque    
                                RoundBox();
                                translate([Thick/2,Thick/2,Thick/2]){     
                                        RoundBox($a=Length-Thick, $b=Width-Thick, $c=Height-Thick);
                                        }
                                        }//Fin diff Coque                            
                                difference(){//largeur Rails        
                                     translate([Thick+m,Thick/2,Thick/2]){// Rails
                                          RoundBox($a=Length-((2*Thick)+(2*m)), $b=Width-Thick, $c=Height-(Thick*2));
                                                          }//fin Rails
                                     translate([((Thick+m/2)*1.55),Thick/2,Thick/2+0.1]){ // +0.1 added to avoid the artefact
                                          RoundBox($a=Length-((Thick*3)+2*m), $b=Width-Thick, $c=Height-Thick);
                                                    }           
                                                }//Fin largeur Rails
                                    }//Fin union                                   
                               translate([-Thick,-Thick,Height/2]){// Cube à soustraire
                                    cube ([Length+100, Width+100, Height], center=false);
                                            }                                            
                                      }//fin soustraction cube median - End Median cube slicer
                               translate([-Thick/2,Thick,Thick]){// Forme de soustraction centrale 
                                    RoundBox($a=Length+Thick, $b=Width-Thick*2, $c=Height-Thick);       
                                    }                          
                                }                                          


                difference(){// wall fixation box legs
                    union(){
                        translate([3*Thick +5,Thick,Height/2]){
                            rotate([90,0,0]){
                                    $fn=6;
                                    cylinder(d=16,Thick/2);
                                    }   
                            }
                            
                       translate([Length-((3*Thick)+5),Thick,Height/2]){
                            rotate([90,0,0]){
                                    $fn=6;
                                    cylinder(d=16,Thick/2);
                                    }   
                            }

                        }
                            translate([4,Thick+Filet,Height/2-57]){   
                             rotate([45,0,0]){
                                   cube([Length,40,40]);    
                                  }
                           }
                           translate([0,-(Thick*1.46),Height/2]){
                                cube([Length,Thick*2,10]);
                           }
                    } //Fin fixation box legs
            }

        union(){// outbox sides decorations
            
            for(i=[0:Thick:Length/4]){

                // Ventilation holes part code submitted by Ettie - Thanks ;) 
                    translate([10+i,-Dec_Thick+Dec_size,1]){
                    cube([Vent_width,Dec_Thick,Height/4]);
                    }
                    translate([(Length-10) - i,-Dec_Thick+Dec_size,1]){
                    cube([Vent_width,Dec_Thick,Height/4]);
                    }
                    translate([(Length-10) - i,Width-Dec_size,1]){
                    cube([Vent_width,Dec_Thick,Height/4]);
                    }
                    translate([10+i,Width-Dec_size,1]){
                    cube([Vent_width,Dec_Thick,Height/4]);
                    }
  
                
                    }// fin de for
               // }
                }//fin union decoration
            }//fin difference decoration
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

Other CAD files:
resources/painel_frontal-v4-perfurado.STL

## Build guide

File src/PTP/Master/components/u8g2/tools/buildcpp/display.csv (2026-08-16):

# 1. device name
# 2. pinset
# 3. constructor name w/o prefix
u8x8_d_ssd1306_128x64_noname | 4WSWSPI | SSD1306_128X64_4W_SW_SPI
u8x8_d_ssd1306_128x64_noname | 4WHWSPI | SSD1306_128X64_4W_HW_SPI
u8x8_d_ssd1306_128x64_noname | 3WSWSPI | SSD1306_128X64_3W_SW_SPI
u8x8_d_ssd1306_128x64_noname | SSDSWI2C | SSD1306_128X64_SW_I2C
u8x8_d_ssd1306_128x64_noname | 6800 | SSD1306_128X64_6800
u8x8_d_ssd1306_128x64_noname | 8080 | SSD1306_128X64_8080

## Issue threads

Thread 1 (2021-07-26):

feature request: rdate time on port 37

markstinson, 2021-07-26:
Please consider implementing the rdate time protocol on port 37 (tcp &/or udp).

Although NTP is better, rdate is "just good enough" in many situations. Due to its simplicity, it's perfect for most IoT and micro-devices. And being a standard, many legacy devices will support rdate over NTP.

It could also be helpful for folks needing a "just good enough" $20 device with a $12 GPS, $4 ESP32 or ESP-8266 & $4 RTC PCF8523.

very cool. cheers.

Montecri, 2022-09-11:
Sorry, for some reason I didn't see your message before. I will work on it, looks really simple.

Would you be able to test once it is done and tell me the results?

Thank you!

Montecri, 2023-04-06:
Hi @markstinson

Just added RDATE support. Please take a look.

Regards,

- Cristiano

Closed 2023-04-09.

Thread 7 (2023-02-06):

Use "timelib.h"

cheise, 2023-02-06:
https://github.com/Montecri/GPSTimeServer/blob/5a0cee3bb3972d495a00e4791f701c804b7f2d9c/src/main.cpp#L653

Why don't you let "timelib.h" calculate it for you?

`timestamp = now() + seventyYears;`

so you don't need all the code for the time calculation.

Montecri, 2023-02-06:
Hi @mmarkin !

Believe you replaced:

` timestamp = numberOfSecondsSince1900Epoch(year(t), month(t), day(t), hour(t), minute(t), second(t));`

with:

`timestamp = CalculateNTP(year(t), month(t), day(t), hour(t), minute(t), second(t));`

On Dual Display tree.

@cheise above is proposing what appears to be a more concise and elegant solution.

I've updated the main tree with the suggestion, tested and appear to work ok.

Would like to implement that on the Dual Display tree?

Thank you!

mmarkin, 2023-02-06:
Hi Cristiano

Thanks for the suggestions. Yes, I should have realized timelib already has
the timestamp. There was no need to calculate it again either by using
ziggy's function or the longer version of it that I wrote. All that has to
be done is to convert timelib's timestamp from UNIX to NTP by adding 70
years.

Also there was no need for the > 3000 age check when syncing with GPS.

I made the changes to my server and it's still working properly. I also
updated the Dual OLED post on GitHub.

Cheers,
Mitch Markin

On Mon, Feb 6, 2023 at 1:05 PM Cristiano Monteiro ***@***.***>
wrote:

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

cheise, 2023-02-07:
In Germany we say: "You can't see the tree for the trees"
or "why make it complicated when it's easy" I hope the translation is correct. Best Regards

mmarkin, 2023-02-07:
In Canada the saying is "you can't see the forest for the trees."  I didn't
write most of the code for this project but I did go through it trying to
make it more efficient. I fixed the bug in the timestamp calculations. But
even though I am very familiar with timelib and  have used it numerous
times for clock projects, it never occurred to me that timelib already has
the timestamp.

Sometimes you get so focused on one solution the obvious easier
solution gets overlooked.

Mitch Markin

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

Montecri, 2023-02-07:
Hi guys!

I remember I added >3000 to debug a specific situation (for which, of course, I don't recall) and forgot to remove it.

Went over the code so many times to make it work with my hardware and specific needs that, at some point, it kind of becomes fuzzy. Unless it's a code-breaking bug you don't see the opportunities anymore. But I was certain that people online would find these and help fix them.

Like my ugly display code, fixed by @mmarkin, and these fixed by @cheise

Thank you all!

- Cristiano

Montecri, 2023-02-07:
Fixed as of today.

cheise, 2023-02-08:
I ported the code to RP2040 Raspberry Pico, the non wifi varriant. That's when I noticed the problems. I have built a lightweight network based GPS NTP device, not WiFi based. Your code helped me a lot to understand many things. Gread work from you :)

Montecri, 2023-02-08:
Very nice!

Have you posted your port on Github or something?

If you want we can created a RP2040 branch for it, like I did for Mitch Dual Display and PIR version, so he can maintain it.

Regards,

- Cristiano

cheise, 2023-03-03:
Under [https://github.com/cheise/PICO_GPS_TimeServer_PLUS](url) you can see my newest public code. Now it has support for the newer TinyGPSPlus libary  ;) This Version is for the i2c Display what you use, too. Functionaly the same, without the "reset / WiFi" Button, i use the "run" pin on RPI Pico for resetting the board with a Button.

Closed 2023-02-07.

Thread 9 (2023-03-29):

Stratum 4? (and a couple of issues/bugs)

sjthespian, 2023-03-29:
I'm playing around with this a bit to see if it will work as a replacement to the RPi I have been running as a time server for many years. One thing that I noticed when I added this as a time server to one of my systems is that it only shows up as stratum 4. From what I know of NTP, shouldn't this be stratum 1 since it is synced directly to GPS?

The ESP device is also showing an odd refid from ntpq -p. From what I know of the spec, that should either be the IP address if this is a stratum 4 server, or either `GPS` or `PPS` if this is stratum 1. The code is setting `GPS`, but since it is sending stratum 4, that gets interpreted as an IP address. So it should probably only set GPS if it is stratum 1, and the IP if it is anything else.

There is bug in how you are setting the root delay and dispersion, your packetBuffer indices are off by 2. The indices are back in sync by the time you set the refid value, so essentially you've shifted those values right by 2 bytes. https://github.com/Montecri/GPSTimeServer/blob/main/src/main.cpp#L642

I'm noticing rather high delay and offset values from this, I'm assuming because it is running over wifi. I'm debating picking up an ethernet shield and seeing if that makes things any better.

Here's an example of ntpq -pn from my server, the GPSTimeServer ESP is running as xxx.xxx.xxx.159 (this is from before I changed it to stratum 1):
```
     remote           refid      st t when poll reach   delay   offset  jitter
==============================================================================
 xxx.xxx.xxx.7      91.82.186.52  2 u    4   16  377    0.642   -0.024   0.055
 xxx.xxx.xxx.1      172.16.42.7   3 u    3   16  377    0.150   -0.184   0.050
 xxx.xxx.xxx.159    71.80.83.0    4 u    2   16  377  140.446  -395.88  29.181
 xxxx:xxxx:xxxx:7  .INIT.        16 u    -   16    0    0.000   +0.000   0.000
*xxxx:xxxx:xxxx:40 .PPS.          1 u   21   64   37   12.056   +0.343   0.189
```

If you're interested, I have a fork in my repo at https://github.com/sjthespian/GPSTimeServer. I've made a few changes like joining an existing wifi network and falling back to AP mode (which I really want to add to the web page at some point), adding more info on the web page, adding syslog support, and cleaning up some of the warnings I was getting (which probably have a lot more to do with the version of the pio tools I'm running than the code).

I would also like to add a text-graph of current satellite info on the web page, but I haven't had time to play with that yet. I'm not sure how badly I want to try and parse that out of the raw GPGSV data.

Montecri, 2023-03-29:
Wow! Great analysis, debugging, and additions!

You're right, it should be Stratum 1. Don't know how I missed that.

Will definitely absorb your fixes and improvements.

Think a web interface with more information and functionalities would be a great addition, especially if the hardcoded defaults could be changed through it. Not a great web designer myself, would need help with that.

Your plans will definitely improve this little project.

Thank you, man! And feel free to reach me anytime.

sjthespian, 2023-03-31:
A couple of new features in my fork:
- It sets the nap data to stratum 16 if not synced, stratum 1 when synced (not tested yet as my server doesn't see it when it isn't synced)
- added support for setting the wifi credentials on the web endpoint and it saves those in a local "filesystem" so they persist across reboots

Now that I have a filesystem, I'm probably going to move the web "homepage" there. I just need to figure out how best to do the templating so I can inject variables into it.

Montecri, 2023-03-31:
Very nice!

Will run some tests this weekend.

Thanks.

- Cristiano

Montecri, 2023-04-01:
Just tested your latest version and you truly made great changes!

Just some points to keep in mind:

- When DEBUG/Serial is activated, either the WIFI_STA (connection to my access point) or the Webserver will not work consistently, sometimes not work at all, at least on my board. As soon as I disable DEBUG (thus, Serial is never initialized and Serial.print never issued) things start working perfectly. For this reason, I changed the line "Serial.print(".");" on enableWifi() to DEBUG_PRINT(".")).

- Perhaps you can include the syslog server name/IP on the variables saved on LittleFS (or I can do it myself), since not everybody will have a syslog server on their network, and the address will probably be different from whatever is in the code.

- Saw you changed U8G2_SH1106_128X64_NONAME_F_HW_I2C with U8G2_SSD1306_128X64_NONAME_F_HW_I2C, believe that's the controller version you got. Can you leave both lines, with the one that doesn't work for you commented? I intend to replace the current version with yours (of course, giving you credits for these improvements) and also take care of people that got the original build parts.

- The dual information screen with short/long press handling is a great addition! However, it is not working reliably :( (everybody that hates button debouncing raises your hand!!!). If you have improved that already, please, let me know so I don't invest time in that.

Thank you for these contributions, now the project is much more useful than before.

Regards,

- Cristiano

Montecri, 2023-04-01:
@mmarkin please keep an eye on this thread, there are some bug fixes and improvements that you probably want to implement on your Dual Display tree.

mmarkin, 2023-04-02:
I had a quick look at sjthespian's code. I haven't had a chance to check it out in detail yet but it looks like there are some good improvements. I was wondering about that Stratum 1 /  Stratum 4 stuff myself.  My version fixed the PlatformIO warnings.  The web server is a nice touch. Yes, since LittleFs is being used the HTML code should be in a file there. It makes it a lot easier to write and maintain the code.

It's good to be able to see the latitude and longitude, too. This is a timeserver, not a navigation aid, but as long as it uses GPS it might as well show where you are!

sjthespian, 2023-04-03:
I have noticed some oddities that I'm trying to track down...

1. The display doesn't always seem to match the GPS status. At the moment for example the display is showing 3 satellites, but looking at the GPS raw GPGSV data I currently have none (it's on my desk inside the house, so it's hit or miss how much sky I get out of the window). I have also seen cases where the GPS debug logs are showing as many as 3 sats but they display still shows zero.
2. Similarly I have seen a couple of cases where the GPS hardware appears to have a sync and the PPS led there is flashing, but the red led I have wired in isn't.

These are both edge cases that most folks will probably never see, but I think it shows an issue with either how things are being updated or how the TinyGPS library is returning data that might have some other impacts.

mmarkin, 2023-04-04:
I changed the code on my server to implement Daniel's packet buffer corrections. I updated the code on the Dual Display branch to show the changes as well. Everything is running properly.  I haven't added the web page yet. It's a nice addition but I don't have a need for it at this time.

I have never seen the front panel red LED and the LED on the GPS board flashing differently on my server.  I'll keep an eye on them, though.

Daniel, did you try disabling the web page that your code servers to see if it runs better? ESP8266s are powerful little devices but they can be overloaded if you try to get them to do too much. Their WiFi functions take up a lot of processing power and sometimes there isn't enough left for other functions. That might be what's causing the glitches with the GPS data.

An NTP clock I built that used an ESP8266 to drive 120 WS2812 LEDs ran fine until I tried to get it to also serve a web page to do some setup. After that, it had problems generating the precise timing needed for the LED data.  I had to upgrade the clock to use an ESP32.

Montecri, 2023-04-04:
>

Weird. On my build, both pps leds blink in sync.

Perhaps making the web server run on the second core would help. I face issues when both Serial and Webserver were being used simultaneously, once I disabled Serial, web server went smoothly.

Working on the short/long/debounce button code, not running reliably for me. Doing some experiments to diagnose if it is a wiring problem or something else. If I can improve the code will update on the main tree together with the other improvements done by @sjthespian.

Thanks!

mmarkin, 2023-04-04:
I have used a library called OneButton written by Matthias Hertel in some of my projects. I find that it works quite well. It handles single clicks, double clicks, short presses, long presses, and debouncing.  You can also specify it the switches are active high or active low. It works best with tactile switches for double clicks, but ordinary momentary pushbuttons work too.

sjthespian, 2023-04-04:
@mmarkin Nice find and easy to implemetn -- it works great and it fixed some of the odd button timing issues I had.  https://github.com/Montecri/GPSTimeServer/commit/8c6080add09e0c2ce6f713b979a62046490bf9e2

@Montecri I think a lot of my performance problems were the debugging I had turned on. Disabling that makes it fly.

I do still want to do something with the web server, but I want to find a way of dealing with embedding variables in the content. If this were python I would just use "f-strings", I haven't found. decent way of doing that with C++ yet.

mmarkin, 2023-04-04:
It's not overly easy to embed C++ variables in a web page if the HTML file is stored with LittleFS.  You should use the Async webserver library and some JavaScript is involved. This tutorial might help. It mentions SPIFFS but LittleFS is the same.  Just substitute LittleFS wherever you see SPIFFS.
https://randomnerdtutorials.com/esp8266-web-server-spiffs-nodemcu/

Montecri, 2023-04-05:
Scrap my suggestion to move the webserver code to the second core. ESP8266 is single core, the dual one is the ESP32. I mixed one for the other.

sjthespian, 2023-04-06:
Thanks! Feel free to close this out, I'll go ahead and merge in your code to my fork.

I started playing with moving the HTML file(s) to LittleFS yesterday, we'll see if I can make any progress with that. I still don't have a good idea on how to do variable substitution in it.

Montecri, 2023-04-06:
Hi!

Just added RDATE support (RFC868) to the main tree. Take a look!

Closed 2023-04-09.

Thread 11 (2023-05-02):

Additional DHCP options to announce NTP Server address.

mfreymond, 2023-05-02:
DHCP has the ability to announce network time servers as part of the DHCP Offer.

Option 004 specifies servers that provide TIME/ITP (as per RFC 868). This is not a recommended protocol/service in a Windows environment.

Option 042 specifies servers that provide NTP/SNTP (RFC 1769). This is the preferred time service in a Windows environment.

By adding these options, pointing to the ESP8266's IP address, some devices would be able to automatically learn the time servers IP address without further configuration.

These DHCP options are specified in the DHCP RFC (RFC 2132).

Montecri, 2023-05-02:
Hi!

Sounds like a very good addition. Will work on that and let this open until done.

Thanks!

mfreymond, 2023-05-02:
I'm not really a developer, but from poking around, it looks like the changes might need to take place in this file:

https://github.com/esp8266/Arduino/blob/master/cores/esp8266/LwipDhcpServer.cpp

Lines 127-138 define the existing options, where they get utilized later on in the code.

Thanks

Closed 2023-06-21.

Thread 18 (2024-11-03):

NTP server does not remember the state of WiFi

rudiyalex, 2024-11-03:
NTP server is connected via ethernet and wifi. I turn off wifi by long pressing the button so that the server works only via ethernet. After rebooting the server, wifi turns on again, and does not remember the last state that it was turned off by the button

Montecri, 2024-11-03:
Good feedback. Will save that in the preferences so it sticks across reboots.

Thanks!

Montecri, 2024-11-16:
Just updated the code. Now it is saving WiFi status to LittleFS and restoring last status on boot.

Please test and let me know.

Thanks & Regards,

- Cristiano

Closed 2024-11-23.

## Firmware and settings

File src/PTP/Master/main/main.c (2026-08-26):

/*
 * ═════════════════════════════════════════════════════════════════════════
 * PTPv2 Grandmaster Server for ESP32-P4
 * ═════════════════════════════════════════════════════════════════════════
 * Cristiano Reis Monteiro <cristianomonteiro@gmail.com> - May/2026
 * ═════════════════════════════════════════════════════════════════════════
 *
 * IEEE 1588-2008, Annex F (L2/Ethernet transport).
 * Target board : Guition JC-ESP32P4-M3-DEV board
 * ESP-IDF      : 5.5.4
 *
 * Build target: PTPv2 GRANDMASTER (master-only firmware).
 *
 * GNSS-disciplined grandmaster: drives the PHC from a 1-PPS edge captured on
 * the GNSS module, transmits Sync / Follow_Up / Announce, and answers
 * Delay_Req from connected slaves.
 *
 * High-level structure of this file (top to bottom):
 *   - Includes
 *   - Configuration #defines, grouped by subsystem
 *   - Type definitions (PTP wire structs, BMCA, servo, LED, GNSS)
 *   - Global state, grouped by subsystem with its protecting lock
 *   - Forward declarations
 *   - Small helpers (time conversion, filter resets, holdover advertise)
 *   - EMAC PHC + PTP wire helpers
 *   - BMCA
 *   - Slave tracking
 *   - PTP message handlers (Delay_Resp, Sync/FollowUp, Announce)
 *   - NMEA parsers (ZDA, RMC, GSV, GSA)
 *   - PPS ISR + pps_task + servo_task  (the timing core)
 *   - Background tasks (gnss, gnss_signal, ptp_rx/tx, heap, watchdog)
 *   - LED status indicator
 *   - OLED display + button
 *   - Network init (DHCP fallback, Ethernet, L2TAP, PHC start)
 *   - Hardware init (GNSS UART, PPS GPIO)
 *   - app_main
 *
 * ─────────────────────────────────────────────────────────────────────────
 * Performance / tuning notes (historical, kept for context)
 * ─────────────────────────────────────────────────────────────────────────
 * PTP is very time-sensitive. If PPS jitter is higher than desired, move the
 * timestamping logic in ptp_rx_task as high as possible after read() returns
 * to capture the state quickly. For a standard L2 implementation on the P4
 * the current structure is already optimized for sub-microsecond accuracy.
 *
 * What GNSS timing mode buys:
 *   - Holdover stability: with much lower PPS jitter, short GNSS outages leave
 *     the master with a far better free-running clock (timing-mode receivers
 *     typically advertise <100 ns holdover for several minutes vs. hundreds
 *     of ns in nav mode).
 *   - Headroom to tighten servo gains. The current acquisition-phase gains
 *     (SERVO_KP=0.4 / SERVO_KI=0.3, used only in SERVO_ACQUIRING; steady-state
 *     uses the much slower KP_SLOW/KI_SLOW pair) were tuned around ~100-200 ns
 *     PPS jitter; with ~10 ns PPS jitter Kp=0.6 / Ki=0.4 and faster lock
 *     acquisition would work without overshoot. Not needed — current
 *     performance is already excellent — but the headroom exists.
 *   - A shorter holdover threshold (currently 5 s) could be used safely
 *     without false alarms: with timing-mode PPS, missing 2 PPS edges
 *     genuinely indicates a problem rather than jitter eating a sample.
 *
 * None of these are required: the system performs at the practical limit of
 * the hardware combination. The takeaway is that GNSS timing mode is the
 * single highest-impact configuration change a PTP grandmaster can make.
 * ═════════════════════════════════════════════════════════════════════════
 */

/* ═════════════════════════════════════════════════════════════════════════
 * Includes
 * ═════════════════════════════════════════════════════════════════════════ */
#include <u8g2.h>
#include "sdkconfig.h"
#include "u8g2_esp32_hal.h"
#include <string.h>
#include <driver/spi_master.h>
#include <stdatomic.h>
#include "esp_timer.h"
#include "esp_heap_caps.h"
#include <inttypes.h>
#include "esp_netif.h"
#include "esp_netif_types.h"
#include <stdio.h>
#include <string.h>
#include <stdlib.h>
#include <errno.h>
#include <sys/fcntl.h>
#include <sys/ioctl.h>
#include <unistd.h>
#include <time.h>
#include <arpa/inet.h>

#include "freertos/FreeRTOS.h"
#include "freertos/task.h"
#include "freertos/queue.h"
#include "freertos/semphr.h"

#include "esp_log.h"
#include "esp_err.h"
#include "esp_app_desc.h" /* esp_app_get_description() — firmware version from version.txt */
#include "esp_event.h"
#include "esp_eth.h"
#include "esp_netif.h"
#include "esp_eth_mac.h"
#include "esp_eth_mac_esp.h"

#include "esp_vfs_l2tap.h"
#include "lwip/prot/ethernet.h"

#include "driver/uart.h"
#include "driver/gpio.h"
#include "esp_rom_sys.h"

#include "u8g2_esp32_hal.h"

#include "allystar_timing.h"
#include "mac_hostname.h" /* deterministic MAC -> hostname (components/mac_hostname) */

/* ═════════════════════════════════════════════════════════════════════════
 * SECTION: Configuration #defines
 *
 * Compile-time constants grouped by subsystem. Servo PI(D) tuning gets the
 * most explanation because it encodes hard-won field-tuning history.
 * ═════════════════════════════════════════════════════════════════════════ */

/* ─── IDF version compatibility ─── */
#ifndef L2TAP_IREC_TYPE_TX_CONFIRM
#define L2TAP_IREC_TYPE_TX_CONFIRM 3
#endif

/* ─── Ethernet / PHY (IP101) ─── */
#define ETH_PHY_ADDR 1
#define ETH_PHY_RST_GPIO 51
#define ETH_MDC_GPIO 31
#define ETH_MDIO_GPIO 52
#define ETH_TYPE_PTP 0x88F7

/* ─── Network / DHCP fallback ───
 * Fallback static IP — used if DHCP doesn't reply in time. Pick a private
 * subnet you don't use elsewhere. */
#define DHCP_FALLBACK_TIMEOUT_MS 30000 /* wait up to 30 s for DHCP */
#define STATIC_IP_ADDR ESP_IP4TOADDR(192, 168, 5, 2)
#define STATIC_IP_NETMASK ESP_IP4TOADDR(255, 255, 255, 0)
#define STATIC_IP_GATEWAY ESP_IP4TOADDR(192, 168, 5, 1)

/* ─── PTP protocol (IEEE 1588-2008) ───
 * Sync cadence is 1 Hz, Announce 0.5 Hz. ptp_tx_task ticks at
 * PTP_SYNC_INTERVAL_MS and sends an Announce every PTP_ANNOUNCE_DIV ticks.
 *
 * NOTE: the on-wire logMessageInterval fields in build_ptp_header() calls
 * (0 for Sync/FollowUp, 1 for Announce) are hardcoded to match these
 * defaults (log2(1s)=0, log2(2s)=1). If you change the intervals to values
 * that no longer satisfy log2(interval_sec) ∈ {0,1}, update those literals
 * in send_sync_and_followup() and send_announce() as well so slaves see
 * the advertised cadence match the actual one. */
#define PTP_SYNC_INTERVAL_MS 1000
#define PTP_ANNOUNCE_INTERVAL_MS 2000

/* Announce-every-N-Sync-ticks divisor, computed at compile time.
 * Round to nearest so a non-integer ratio picks the closest viable cadence. */
#define PTP_ANNOUNCE_DIV \
    (((PTP_ANNOUNCE_INTERVAL_MS) + (PTP_SYNC_INTERVAL_MS) / 2) / (PTP_SYNC_INTERVAL_MS))

_Static_assert(PTP_SYNC_INTERVAL_MS > 0,
               "PTP_SYNC_INTERVAL_MS must be positive");
_Static_assert(PTP_ANNOUNCE_INTERVAL_MS >= PTP_SYNC_INTERVAL_MS,
               "PTP_ANNOUNCE_INTERVAL_MS must be >= PTP_SYNC_INTERVAL_MS "
               "(the tx task ticks at the Sync rate)");
_Static_assert(PTP_ANNOUNCE_DIV >= 1,
               "PTP_ANNOUNCE_DIV must be >= 1 (check the two intervals)");
// Defined at task creation
// #define PTP_TASK_PRIORITY 5
#define PTP_DOMAIN 0

#define PTP_FLAG_TWO_STEP 0x0200

/* TimePropertiesDS flags (IEEE 1588-2008) */
#define PTP_FLAG_LEAP61 (1 << 0)
#define PTP_FLAG_LEAP59 (1 << 1)
#define PTP_FLAG_UTC_OFFSET_VALID (1 << 2)
#define PTP_FLAG_PTP_TIMESCALE (1 << 3)
#define PTP_FLAG_TIME_TRACEABLE (1 << 4)
#define PTP_FLAG_FREQ_TRACEABLE (1 << 5)

/* PTP message types (messageType field) */
#define PTP_MSG_SYNC 0x0
#define PTP_MSG_DELAY_REQ 0x1
#define PTP_MSG_FOLLOW_UP 0x8
#define PTP_MSG_DELAY_RESP 0x9
#define PTP_MSG_ANNOUNCE 0xB

#define ANNOUNCE_TIMEOUT_SEC 6

/* ─── BMCA ─── */
#define BMCA_STABILITY_THRESHOLD 3

/* ─── Slave tracking — count distinct slave clock IDs seen in last N sec ─── */
#define SLAVE_TRACK_MAX 8      /* max simultaneously-tracked slaves */
#define SLAVE_TIMEOUT_MS 30000 /* a slave is "active" if seen <30s ago */

/* ─── GNSS UART + PPS pins ─── */
#define GNSS_UART_NUM UART_NUM_1
#define GNSS_TX_PIN 33
#define GNSS_RX_PIN 32
#define PPS_GPIO 20

/* ─── Holdover ─── */
#define HOLDOVER_TIMEOUT_SEC 5

/* Post-holdover settling: keep advertising clockClass 7 until the servo
 * has been continuously LOCKED for this long after GNSS recovery. Prevents
 * downstream ptp4l clients from reacquiring/railing their servo while our
 * PHC is still settling from a COARSE STEP. */
#define POST_HOLDOVER_SETTLE_MS 30000 /* 30 s */

/* ─── Servo PI(D) tuning ───
 *
 * Two gain sets exist. The "fast" (KP/KI) pair is used during acquisition;
 * the "slow" (KP_SLOW/KI_SLOW/KD_SLOW) pair is the steady-state servo.
 *
 * PID tuning — KD term added to handle thermal transients.
 *
 *   KP_SLOW = 0.05     — proportional, responds to current averaged offset
 *   KI_SLOW = 0.001    — integral, learns crystal drift (~1000 s / ~17 min
 *                        timescale: 1/KI at the 1 Hz sample rate)
 *   KD_SLOW = 2.0      — derivative, reacts to rate of drift change
 *   D_WINDOW = 10      — derivative computed as slope of averaged offset
 *                        over the last 10 seconds, smoothing noise spikes.
 *
 * The D term is critical for tracking thermal transients during boot
 * warmup, where the crystal's natural frequency changes by hundreds of
 * ppb/sec. The integrator (KI) alone is too slow to catch this; the
 * derivative term sees the offset moving and adds immediate frequency
 * correction proportional to *how fast* it's diverging.
 *
 * Simulation against the actual recorded thermal-transient log:
 *   PI  (no D):  max avg offset 5,940 ns, lingering steady-state error
 *   PID (KD=2):  max avg offset 5,260 ns, drives to zero
 *
 * Steady-state (±300 ns receiver noise, 1 hour after settling, partially
 * obstructed sky view, urban jungle):
 *   30% of time within ±300 ns of true GNSS time
 *   74% of time within ±1 µs
 *   89% of time within ±2 µs
 *   Mean error -74 ns.
 *
 * SERVO_KD_ENABLE gates the D term off by default (set to 1 to re-enable). */
#define SERVO_KP 0.4 // was 0.7
#define SERVO_KI 0.3
#define SERVO_KP_SLOW 0.05
#define SERVO_KI_SLOW 0.001
#define SERVO_KD_SLOW 2.0
#define SERVO_D_WINDOW 10 /* derivative smoothing samples */
#define ADJ_SLEW_PPB_PER_S 100.0
#define SERVO_KD_ENABLE 0 // set to 1 to re-enable D term

/* Hardware output clamp for the PHC frequency adjustment. The ESP32-P4
 * EMAC accepts adjustments in the ±500,000 ppb (±500 ppm) range. The
 * actual crystal needs ~50 ppm of correction, so this is a sanity rail
 * to prevent runaway, not a tuning parameter. */
#define SERVO_FREQ_LIMIT_PPB 500000.0

/* ─── Servo lock-acquisition criteria ───
 *
 * Three conditions must all hold for LOCK_THRESHOLD consecutive samples
 * before SERVO_LOCKED is declared:
 *   1. |offset|                < LOCK_OFFSET_NS        (phase converged)
 *   2. |offset - prev_offset|  < LOCK_FREQ_DELTA_NS    (frequency converged)
 *   3. Count of (1)&(2) being true ≥ LOCK_THRESHOLD    (sustained)
 *
 * Phase 5 µs: prior good runs showed steady-state ±500 ns offset. A 5 µs
 * gate guarantees we don't declare lock while the servo is still
 * mid-correction, but is loose enough that normal sample-to-sample PPS
 * jitter doesn't bounce us out.
 *
 * Frequency 2 µs delta: PI servo at steady state moves the filtered
 * offset by under 1 µs/sample. A 2 µs gate excludes the settling phase
 * (where consecutive samples may differ by 100+ µs).
 *
 * Threshold LOCK_THRESHOLD = 8, applied as `stable_count > LOCK_THRESHOLD` in
 * servo_task, so lock is actually declared on the 9th consecutive sample
 * (≈9 seconds): with both phase + freq gated, this is solid evidence of
 * convergence without being painfully slow. */
#define LOCK_THRESHOLD 8
#define LOCK_OFFSET_NS 5000LL
#define LOCK_FREQ_DELTA_NS 2000LL

/* ACQUIRING sanity rail. A pre-lock offset beyond this bound cannot come
 * from normal acquisition (worst legitimate case is ~2.5 s: coarse-step
 * granularity plus a stale sentence_offset); it means the PHC or the GNSS
 * reference moved out from under the acquisition — a PPS edge captured
 * during an EMAC restart window, a receiver power-cycle, or a garbage
 * coarse step. ACQUIRING has no other exit path, so servo_task restarts
 * acquisition from UNLOCKED after ACQ_RAIL_STRIKES consecutive
 * beyond-rail samples (a lone outlier is skipped, not punished). */
#define MAX_STEP_NS 10000000000LL /* 10 s */
#define ACQ_RAIL_STRIKES 3

/* Consecutive HARD_REJECTs in SERVO_LOCKED that force a full re-acquire.
 * Defined here (not inside servo_task) so render_screen_servo, which is
 * defined earlier in the file, can display the streak against this limit. */
#define REJECT_STREAK_REACQUIRE 45
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
void app_main(void)
{
    // If your loggin is not working (nothing is being produced at serial output), look at sdkconfig.defaults to know why
    // and re-enable it, if desired
    esp_log_level_set("*", ESP_LOG_INFO);
    // esp_log_level_set("*", ESP_LOG_WARN);
    //  esp_log_level_set("PTP_SERVER", ESP_LOG_INFO);

    u8g2_esp32_hal_t u8g2_esp32_hal = U8G2_ESP32_HAL_DEFAULT;
    u8g2_esp32_hal.bus.i2c.sda = PIN_SDA;
    u8g2_esp32_hal.bus.i2c.scl = PIN_SCL;
    u8g2_esp32_hal_init(u8g2_esp32_hal);

    u8g2_Setup_sh1106_i2c_128x64_noname_f(&u8g2, U8G2_R0,
                                          // u8x8_byte_sw_i2c,
                                          u8g2_esp32_i2c_byte_cb,
                                          u8g2_esp32_gpio_and_delay_cb); // init u8g2 structure

    u8x8_SetI2CAddress(&u8g2.u8x8, 0x78);
    // u8x8_SetI2CAddress(&u8g2.u8x8, 0x3C << 1);

    ESP_LOGI(TAG, "u8g2_InitDisplay");
    u8g2_InitDisplay(&u8g2); // send init sequence to the display, display is in
                             // sleep mode after this,

    /* Record boot time for uptime display */
    g_boot_time_ms = esp_timer_get_time() / 1000;

    /* Launch button + display tasks (low priority — never block timing-critical work) */
    xTaskCreate(button_task, "btn", BUTTON_TASK_STACK, NULL, BUTTON_TASK_PRIO, NULL);
    xTaskCreate(display_task, "display", DISPLAY_TASK_STACK, NULL, DISPLAY_TASK_PRIO, NULL);

    /* ─────────────────────────────────────────────────────────────────────
     * Order matters: every dependency of pps_isr_handler must exist BEFORE
     * pps_init() arms the GPIO interrupt. The handler does:
     *     emac_get_time(&ts)       → esp_eth_ioctl(g_eth_hndl, ...)
     *     xSemaphoreGiveFromISR(g_pps_sem, ...)
     * so g_pps_sem must be created and g_eth_hndl must be populated (i.e.
     * ethernet_init + esp_eth_start completed) before the first edge can
     * possibly fire. Otherwise a PPS pulse landing in this window — or a
     * floating PPS pin firing on noise when no GNSS module is attached —
     * dereferences NULL inside the ISR and panics the box at boot.
     * ───────────────────────────────────────────────────────────────────── */

    g_eth_up_sem = xSemaphoreCreateBinary();
    g_pps_sem = xSemaphoreCreateBinary();

    /* Serializes the shared L2TAP fd across delay_resp_task + ptp_tx_task.
     * Must exist before any l2tap_send_ptp call (the PTP tasks below). */
    g_l2tap_tx_mtx = xSemaphoreCreateMutex();

    /* DHCP-fallback machinery — created BEFORE esp_eth_start so IP_EVENT_
     * ETH_GOT_IP can never fire while g_got_ip_sem is still NULL (the
     * handler NULL-guards, but a silently dropped give would look like
     * "DHCP never answered" and push a perfectly good lease onto the
     * static fallback 30 s later). The task starts now too, so its
     * first-cycle drain runs before any link can possibly come up and a
     * genuinely early GOT_IP can't be mistaken for a stale one from a
     * previous cycle. Until link-up the task only polls g_link_up at
     * 500 ms — it touches no netif state before ethernet_init sets it. */
    g_got_ip_sem = xSemaphoreCreateBinary();
    g_link_down_sem = xSemaphoreCreateBinary();
    xTaskCreate(dhcp_fallback_task, "dhcp_fb", 3072, NULL, 2, NULL);

    /* Ethernet driver init + start. Will not block waiting for link.
     * Fatal driver/netif failures abort inside ethernet_init via
     * ESP_ERROR_CHECK; a non-OK return here means only the OPTIONAL
     * hostname derivation failed — the device remains a fully functional
     * grandmaster, it just appears under the default lwIP name (and
     * g_hostname stays empty, which every consumer already guards). */
    esp_err_t eth_init_err = ethernet_init();
    if (eth_init_err != ESP_OK)
        ESP_LOGW("MAIN",
                 "ethernet_init: hostname derivation failed (%s) — "
                 "continuing with default hostname",
                 esp_err_to_name(eth_init_err));
    ESP_ERROR_CHECK(esp_eth_start(g_eth_hndl));
    ESP_LOGI("ETH", "Ethernet started (link state will be reported on connect)");

    /* Install the hostname NOW -- after esp_eth_start() so lwIP has
     * fully wired the netif, and before the first DHCP DISCOVER so the
     * unit appears under its stable name in leases from the first
     * transaction.  The hostname persists on the netif for the whole
     * app lifetime -- surviving cable unplug/replug and DHCP restarts
     * without any per-event re-application.  Logging (success and the
     * specific CONFIG_LWIP_MAX_HOSTNAME_LEN hint on failure) is owned
     * by the component. */
    if (g_hostname[0])
        mac_hostname_apply(g_eth_netif, g_hostname);

    /* Now safe to arm the PPS GPIO interrupt: g_pps_sem and g_eth_hndl exist. */
    pps_init();

    /* Start the LED subsystem BEFORE timing_core_bringup, so that if bring-up
     * fails it can surface LED_STATE_FAULT to a running LED task. Initial state
     * is NO_LINK (no peer yet); the servo will move it to ACQUIRING/LOCKED as it
     * disciplines to GNSS, independent of link. */
    led_start();
    led_set_state(LED_STATE_NO_LINK);
    xTaskCreate(pps_led_task, "pps_led", 2048, NULL, 1, NULL);

    /* Bring up the timing core NOW — driver is started, so the PHC and L2TAP
     * can come up without waiting for a peer/link. This is the architectural
     * decoupling: GNSS disciplining begins at power-on, and PTP serving begins
     * later, whenever a link appears, finding the clock already locked.
     *
     * On failure, timing_core_bringup sets LED_STATE_FAULT and returns false;
     * g_phc_ready stays false so the timing tasks remain safely parked. We do
     * NOT abort app_main — OLED/LED/web diagnostics still run so the failure is
     * visible. */
    if (!timing_core_bringup())
    {
        ESP_LOGE("MAIN", "Timing core bring-up FAILED — clock will not discipline");
    }

    /*
     * NOTE: Promiscuous mode REMOVED.
     *
     * The original code enabled promiscuous mode to debug Linux interop.
     * For normal operation, the EMAC accepts:
     *   - Frames addressed to its unicast MAC (e.g., DHCP responses)
     *   - Frames to known multicast groups (PTP MCAST 01:1B:19:00:00:00 is
     *     accepted via the multicast filter set up by L2TAP)
     *   - Broadcasts (DHCP, ARP)
     *
     * Disabling promiscuous mode roughly halves RX load on a busy network
     * and substantially reduces pressure on the EMAC RX descriptor pool —
     * which was the cause of the "no mem for receive buffer" errors after
     * extended uptime.
     *
     * If you ever need to re-enable for debugging, uncomment:
     *
     *   bool promisc = true;
     *   esp_eth_ioctl(g_eth_hndl, ETH_CMD_S_PROMISCUOUS, &promisc);
     *   ESP_LOGI("ETH", "Promiscuous mode: ON");
     */

    /* GNSS UART can come up immediately — independent of network */
    gnss_uart_init();
    uart_flush(GNSS_UART_NUM);

    /* Kick off the TAU1201 timing-mode configurator. Runs as its own task,
     * shares the GNSS UART RX stream via allystar_timing_feed_data() which is
     * called from gnss_task. Fails are reported via the callback and the
     * OLED auto-jumps to screen 5. */
    initialize_allystar_timing_service(timing_config_error_cb);

    /* (DHCP-fallback semaphores + task were created earlier, before
     * esp_eth_start — see the ordering comment there.) */

    /* Launch all tasks now. They self-gate on g_phc_ready (timing core:
     * servo, pps) and on g_link_up / g_l2tap_ready (PTP packet I/O). */

    /* Delay_Resp producer/consumer: create the queue and worker BEFORE the RX
     * task, so enqueue_delay_req always has a valid queue. Worker priority 6
     * sits below the RX receive loop (7) and at/above the Sync/Announce TX
     * task (5), so receiving and Sync cadence both win over Delay_Resp under
     * flood. */
    g_delay_resp_q = xQueueCreate(DELAY_RESP_Q_DEPTH, sizeof(delay_resp_job_t));
    xTaskCreate(delay_resp_task, "dresp", 4096, NULL, 6, NULL);

    xTaskCreate(ptp_rx_task, "ptp_rx", 8192, NULL, 7, NULL);
    xTaskCreate(ptp_tx_task, "ptp_tx", 8192, NULL, 5, NULL);

    xTaskCreate(gnss_task, "gnss", 6144, NULL, 5, NULL);
    xTaskCreate(gnss_signal_task, "gnss_sig", 3072, NULL, 1, NULL);
    xTaskCreate(servo_task, "servo", 6144, NULL, 6, &servo_task_handle);
    xTaskCreate(pps_task, "pps_task", 4096, NULL, 7, NULL);

    xTaskCreate(heap_monitor_task, "heap_mon", 3072, NULL, 1, NULL);

    xTaskCreate(watchdog_task, "wdt", 4096, NULL, 1, NULL);

    ESP_LOGI("MAIN", "All tasks launched. Waiting for Ethernet link...");
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

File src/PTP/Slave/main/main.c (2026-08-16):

/*
 * ═════════════════════════════════════════════════════════════════════════
 * PTPv2 Slave for ESP32-P4
 * ═════════════════════════════════════════════════════════════════════════
 * Cristiano Reis Monteiro <cristianomonteiro@gmail.com> - May/2026
 * ═════════════════════════════════════════════════════════════════════════
 *
 * ─────────────────────────────────────────────────────────────────────────
 * Build target: PTPv2 SLAVE (slave-only firmware)
 * IEEE 1588-2008, Annex F (L2/Ethernet transport)
 * Target board: Guition JC-ESP32P4-M3-DEV board
 * ESP-IDF Version: 5.5.4
 *
 * PTP-only slave: locks onto a remote grandmaster via Sync / Follow_Up /
 * Delay_Req / Delay_Resp, disciplines the local PHC to the master's clock.
 * No GNSS, no PPS edge capture, no Sync/Announce transmission.
 * ─────────────────────────────────────────────────────────────────────────
 *
 * ─────────────────────────────────────────────────────────────────────────
 * How the code runs at a glance
 *
 * On boot, app_main captures start time, creates sync primitives, then:
 *   1. ethernet_init()      — brings up the Ethernet driver, derives the
 *                             device hostname from the MAC (mac_hostname
 *                             component) and installs it BEFORE the first
 *                             DHCPDISCOVER so the router lists us by name,
 *                             attaches netif glue for L2TAP RX
 *   2. timing_core_bringup()— captures MAC + clockIdentity, opens the L2TAP
 *                             socket, enables the ESP32-P4's PHC hardware
 *                             timestamping, sets g_phc_ready
 *   3. Task spawn           — see task list below
 *   4. web_server_start()   — /health, /api/status JSON, OTA endpoint
 *
 * The PTP data path (bottom-up):
 *   1. Wire RX  → ptp_rx_task decodes Ethernet frames arriving on L2TAP
 *   2. Handlers → capture T1/T2/T3/T4 timestamps and Announce properties;
 *                 BMCA (Best Master Clock Algorithm) picks the best
 *                 observed grandmaster and stability-filters GM identity
 *   3. Servo   → slave_compute_and_apply does the four-timestamp offset
 *                 math (offset = ((t2-t1) - (t4-t3)) / 2) and either steps
 *                 the PHC (large offset, pre-lock) or nudges its frequency
 *                 via a PI controller (small offset, in-lock)
 *   4. Consumers → OLED (4 screens), LED (state machine), web /api/status,
 *                 and periodic gm_diag console reports all read the outputs
 *                 of the servo + GM tracking
 *
 * Background tasks (all lower priority than PTP RX):
 *   ptp_rx_task            — L2TAP read loop; dispatches to handlers
 *   delay_req_task         — drains g_delay_req_q; keeps PHC ioctls off the
 *                            RX hot path
 *   gm_diag_task           — periodic GM quality/health summary to console
 *   slave_watchdog_task    — self-heals via emac_restart_preserve_phc() if
 *                            the PHC stops advancing
 *   slave_led_task         — drives the status LED pattern from s_led_state
 *   slave_led_watch_task   — transitions LED state on Sync freshness
 *                            (LOCKED / HOLDOVER / FAULT)
 *   pps_led_task           — pulses a second LED on every Sync RX (heartbeat)
 *   display_task           — 4-screen OLED render loop at ~2 Hz
 *   button_task            — debounced screen-cycle button
 *   dhcp_fallback_task     — long-lived; applies static IP if DHCP times out
 *
 * OLED screens (button cycles):
 *   1. Main         — lock state, offset (auto-scaled ns/µs), path delay,
 *                     sync-rate label (derived from GM's logSyncInterval)
 *   2. Servo        — lock duration, offset/delay mean±sd, Q100/Q1k quality,
 *                     freq-adjust ppb + linreg drift slope, asymmetry
 *   3. Network      — link + IP + L2TAP-ready flag, hostname (2 rows),
 *                     uptime + free heap
 *   4. Grandmaster  — full GM MAC + stepsRemoved, BMCA fields
 *                     (priority1/2, clockClass, accuracy), time source +
 *                     UTC offset, Sync freshness + delay-path health + !N
 * ─────────────────────────────────────────────────────────────────────────
 *
 * ─────────────────────────────────────────────────────────────────────────
 * File layout (17 sections)
 *
 *   Section 1  — Includes
 *   Section 2  — Configuration #defines (grouped by subsystem)
 *   Section 3  — Type definitions (PTP wire structs, state enums, GM diag)
 *   Section 4  — Global state (grouped by owning subsystem)
 *   Section 5  — Forward declarations (single block so any function may
 *                call any other regardless of emission order)
 *   Section 6  — Small helpers (pure functions, math utilities, PHC read)
 *   Section 7  — EMAC PHC + PTP wire helpers (timestamp encode/decode,
 *                header build, L2TAP send with HW TX timestamping)
 *   Section 8  — BMCA (compares Announces, picks best observed GM)
 *   Section 9  — PTP message handlers (Sync, FollowUp, DelayResp, Announce
 *                + the Delay_Req producer/consumer pair)
 *   Section 10 — Servo + lock management (PI controller, step vs freq
 *                decision, reject streak → reacquire, ever-locked latch)
 *   Section 11 — Background tasks (ptp_rx_task, delay_req_task, gm_diag)
 *   Section 12 — Health monitoring (heap watchdog + EMAC restart preserving
 *                the PHC clock)
 *   Section 13 — LED status indicator (state machine → pattern) + PPS LED
 *   Section 14 — OLED display + 4-screen renderer + debounced button
 *   Section 15 — Network initialization (Ethernet driver, DHCP with static
 *                fallback, MAC-derived hostname, link up/down handling)
 *   Section 16 — Hardware initialization (PHC enable/verify, timing_core
 *                bringup called once from app_main)
 *   Section 17 — app_main (entry point)
 * ─────────────────────────────────────────────────────────────────────────
 */

/* ═════════════════════════════════════════════════════════════════════════
 * SECTION 1: Includes
 * ═════════════════════════════════════════════════════════════════════════ */

#include <u8g2.h>
#include "sdkconfig.h"
#include "u8g2_esp32_hal.h"
#include <string.h>
#include <driver/spi_master.h>
#include <stdatomic.h>
#include "esp_timer.h"
#include "esp_heap_caps.h"
#include <inttypes.h>
#include "esp_netif.h"
#include "esp_netif_types.h"
#include "mac_hostname.h"
#include <stdio.h>
#include <string.h>
#include <stdlib.h>
#include <errno.h>
#include <sys/fcntl.h>
#include <sys/ioctl.h>
#include <unistd.h>
#include <time.h>
#include <arpa/inet.h>

#include "freertos/FreeRTOS.h"
#include "freertos/task.h"
#include "freertos/queue.h"
#include "freertos/semphr.h"

#include "esp_app_desc.h"
#include "esp_log.h"
#include "esp_err.h"
#include "esp_event.h"
#include "esp_eth.h"
#include "esp_netif.h"
#include "esp_eth_mac.h"
#include "esp_eth_mac_esp.h"
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

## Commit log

2021-09-20 Update README.md
    Added leds and resistors with their values to part list, since I used standard (fixed values) resistors on fritzing diagram.
2022-08-09 NTP date calculation fix
    Fixed NTP date calculation.
    Thanks to Mitch Markin for spotting that and suggesting a fix.
    [main.cpp]
2023-02-06 cheise suggestions
    - Fixed >3000 update condition
    - More elegant timestamp calculation on NTP
    [main.cpp]
2023-03-18 New formats for 3D printing
    [painel_frontal-v4-perfurado.SLDPRT, painel_frontal-v4-perfurado.STL, painel_frontal-v4.DXF]
2023-04-06 Updated with new functionalities and bug fixes
    Added syslog
    Added LittleFS
    Added WiFi client functionality
    Improved Webpage
    Fixed NTP code
    Added dual functionality for screen and button
    All suggestions from @sjthespian
2023-04-06 Updated with new functionalities and fixes
    Added Syslog
    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
    [main.cpp]
2023-04-09 Fixes and features
    Fixed Lat Lng display
    Added GPS sync status feedback through green led
    [main.cpp]
2023-04-09 Fixes and new features
    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
2023-04-10 Updated power supply schematics and parts list
2023-08-23 ESP32 port
    New functionalities coming with ESP32 port.
2023-08-23 ESP32 port
    ESP32 port and new functionalities.
2023-10-13 OpenSCAD and DXF QR Code files
    [Case_Ver2.scad, qr-code6.dxf]
2023-10-13 STL Files
    [Case_Ver2-BPanel.stl, Case_Ver2-Bottom.stl, Case_Ver2-FPanel.stl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]
2023-12-21 Update ota.h
    Changed button color to a more pleasant one
2026-08-16 Added ESP32 Wiring Diagram
    Added ESP32 Wiring Diagram (No Ethernet)
2026-08-16 Added Fritzing file for ESP32
    Added Fritzing file for ESP32 (No Ethernet)
    [sketch-ESP32_Without_ETH-20250308.fzz]
2026-08-16 Added Fritzing PNG export for ESP32
    Added Fritzing PNG export for ESP32 (No Ethernet)
2026-08-16 Added ESP32 With Ethernet Wiring Diagram
    Added ESP32 With Ethernet Wiring Diagram
2026-08-16 Added ESP32 With Ethernet Fritzing Wiring Diagram
    Added ESP32 With Ethernet Fritzing Wiring Diagram
    [sketch-ESP32_With_ETH-20250308.fzz]
2026-08-16 Added ESP32 With Ethernet Fritzing PNG Export
    Added ESP32 With Ethernet Fritzing PNG Export Wiring Diagram
2026-08-16 W5500 Fritzing Part Fixed
    For some reason, W5500 built by vaneapp (https://forum.fritzing.org/u/vanepp/summary) was not showing the pin labels when dropped on the breadboard. I manually fixed that by exporting the icon and label as SVG, recombining them together, exporting as a new SVG, changing the part image on Fritzing 1.0.1 to the new SVG and updating the pin connectors. Here you find the final resulting part.
2026-08-16 Fixed syslog issue and added more resilience to file handling
    Fixed syslog issue and added more resilience to file handling
    [main.cpp]
2026-08-16 Finalized PTPv2 Initial - Done
    Finalized PTPv2 Initial - Done
    [board.dxf, clock.dxf, clock_2.dxf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]
2026-08-16 Change target from esp32 to esp32p4 in CI workflow
2026-08-16 Change target from esp32 to esp32p4 in workflow
2026-08-16 Fixed NTP_RDATE files structure
    [main.cpp]
2026-08-16 Critical path decoupler + OTA Basic Auth + Bug Fixes
    [main.c, web_server.h]
2026-08-16 OpenSCAD case files and project QR Code logo added
    [Case_PTP-FINAL.scad, qr-code6.dxf]
2026-08-16 Initial
    First commit of PTP Slave
    [partitions_ota.csv]
2026-08-16 Add u8g2 component for slave display
    [board.dxf, clock.dxf, clock_2.dxf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]
2026-08-16 The hostnamer
    - Several bugs corrected and protocol adherence improvements
    - Updated variables names to refer to GNSS as oposed to GPS only
    - - More code cleanup
    - Dynamic, collision free, hostname generation
    [allystar_timing.c, main.c]
2026-08-26 Fixed stellites in view / used count.
    Refactor GSV and GGA parsing logic for improved clarity and correctness. Update variable names and comments for better understanding.
    [main.c]
2026-10-27 Add wiring instructions for Guition JC-ESP32P4-M3-DEV (#28)
    Added wiring section for Guition JC-ESP32P4-M3-DEV with diagram.
2026-11-01 BMCA refinements and bug fixes
    - Select the best master with valid time.
    - Ignore timing messages from other masters.
    - Stop using masters that stop announcing.
    - Filter timing spikes using recent offsets and path delays.
    - Allow slow clock drift without repeated lock loss.
    - Hold the learned clock frequency while rejecting bad samples.
    - Recover from master time changes without repeated clock steps.
    - Drop lock when the master loses time traceability.
    - Simplify lock handling and frequency updates.
    - Increase stack space for LED, PPS LED, and button tasks.
    - Add the BMCA test bench with logs and reports.
    - Add password-protected remote reboot.
    - Block remote reboot during firmware uploads.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
2026-11-01 Improvements and bug fixes related to BMCA and clock smoothing
    - Added a BMCA dashboard showing master selection, peer clocks, and role changes.
    - Added API controls to change PTP priorities without restarting.
    - Improved status data and fixed the lock quality display.
    - Fixed slow or failed GNSS lock acquisition.
    - Improved recovery after GNSS signal loss.
    - Prevented missing or extra PPS pulses from shifting the clock by whole seconds.
    - Added checks for whole-second differences between GNSS and the clock.
    - Smoothed small timing corrections after signal recovery.
    - Increased task stack space and made BMCA logs more visible.
    - Added password-protected remote reboot.
    - Added wiring diagrams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
2026-11-01 Change target from esp32 to esp32p4 in CI workflow
    Fixes for explicit esp32p54 target.
